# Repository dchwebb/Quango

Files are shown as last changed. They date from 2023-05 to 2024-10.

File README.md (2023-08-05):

# Quango
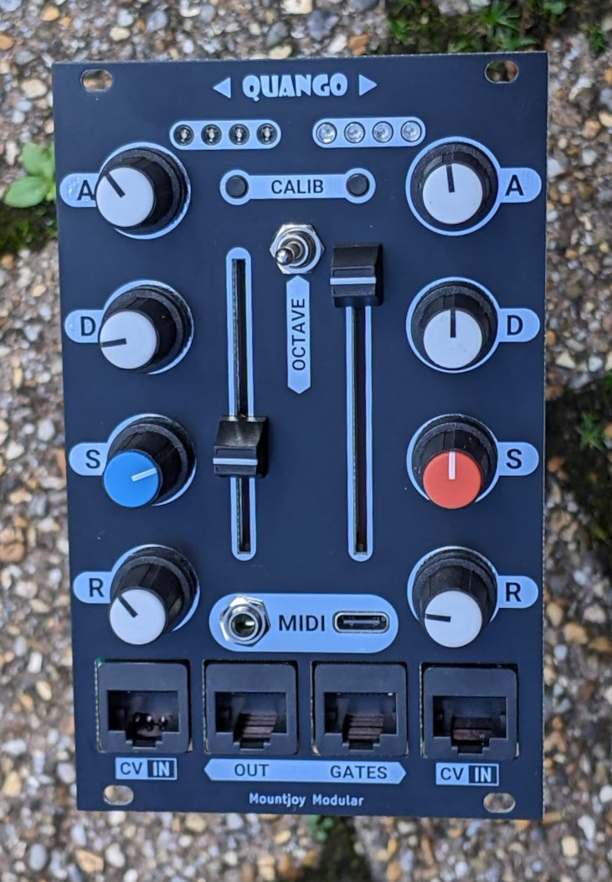
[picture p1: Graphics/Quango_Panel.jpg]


Quango
--------

Quango is a combined MIDI interface, VCA and envelope for controlling four voice polyphonic Eurorack Modular Oscillators. Polyphonic signal interconnections are made via RJ-45 cables (ie Ethernet cables).

Quango can control two VCOs simultaneously, supplying 1V/Octave pitch information and then shaping the returned audio using 8 ADSR envelopes controlling VCAs for each voice.

The MIDI interface receives both USB and serial MIDI data and also features a calibration mechanism where the pitch CV for each voice is adjusted to correct any tuning errors.

Each of the two channels uses an RJ-45 connector to send CV data on lines 1-4 and receive audio data on lines 5-8. The received audio data is used both for pitch calibration and sent into the ADSR-controlled VCAs.

Both channel voices are mixed and output onto an RJ-45 connection. Additionally each channel's four voices can be separately output on a header on the back of the unit. the gate signal for each voice is also output on an RJ-45 for controlling external envelopes etc.

Additional controls include an octave switch to allow channel B's CV range to be adjusted up or down an octave and a fader to control the overall level of each voice. LEDs show the current level of the VCA of each voice for each channel.

Technical
---------

Quango uses an STM32G473 microcontroller which handles the MIDI interfacing, generates 12-bit DAC signals to control the envelopes, reads the front panel controls from its internal ADCs and controls two external DACs for generating the pitch CV and one envelope (the microcontroller has 7 internal 12 bit DACs so the 8th envelope is supplied from an external 12 bit DAC).

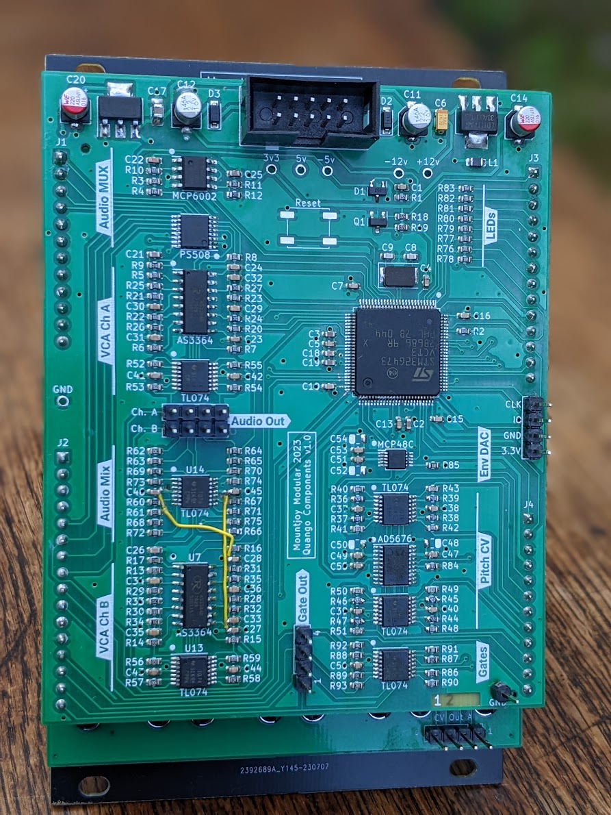
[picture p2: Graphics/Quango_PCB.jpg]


The 1V/Octave Pitch output is generated using an SPI controlled 16-bit 8 channel Analog Devices AD5676 DAC. A Microchip MCP48 12 bit DAC outputs the one envelope generated externally to the microcontroller. Alfa AS3364 quad linear VCAs are used for independent level control of each channel.

A PS508 audio multiplexer switches the 8 audio input channels to a single ADC channel on the microcontroller for pitch detection. Output level LEDs are controlled via PWM from the microcontroller.

Construction is a sandwich of three PCBs with a component board, a controls board and a panel. PCBs designed in Kicad v6.

[Components schematic](https://raw.githubusercontent.com/dchwebb/Quango/master/Hardware/Quango_Components.pdf)

[Controls schematic](https://raw.githubusercontent.com/dchwebb/Quango/master/Hardware/Quango_Controls.pdf)

In addition the the Eurorack +/-12V rails (which have polarity protection and filtering) a 5v rail is supplied using an AMS1117-5.0 LDO. A 3.3v rail is generated with an LM1117-3.3.

Errata
------

Version 1 of the component PCB had the power supply connections to op-amp U14 reversed.

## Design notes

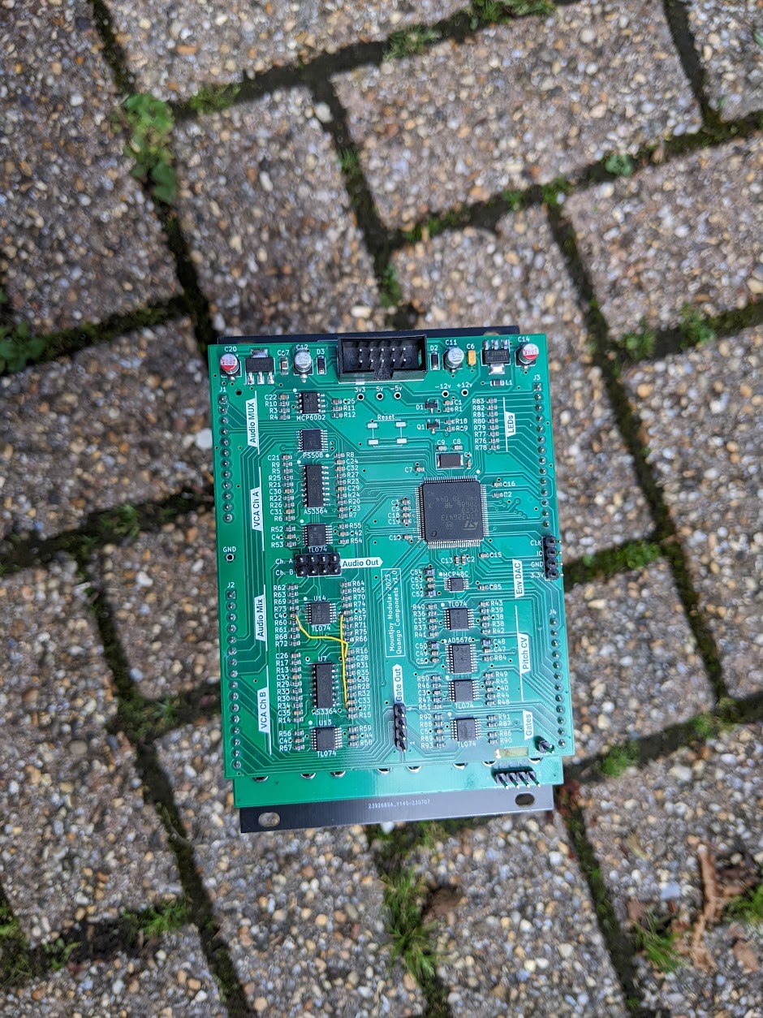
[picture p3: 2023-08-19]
Graphics/Quango_PCB2.jpg

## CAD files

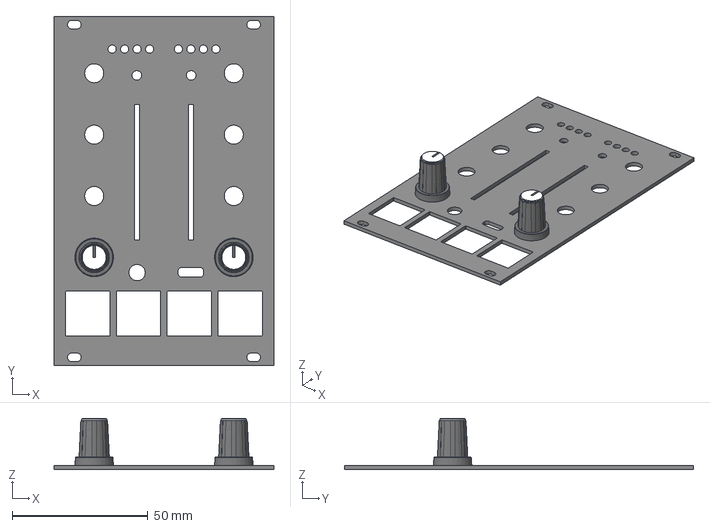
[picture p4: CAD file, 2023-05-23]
Hardware/Quango_Panel.step
81.0 x 128.5 x 18.9 mm
_autosave-Quango_Panel PCB

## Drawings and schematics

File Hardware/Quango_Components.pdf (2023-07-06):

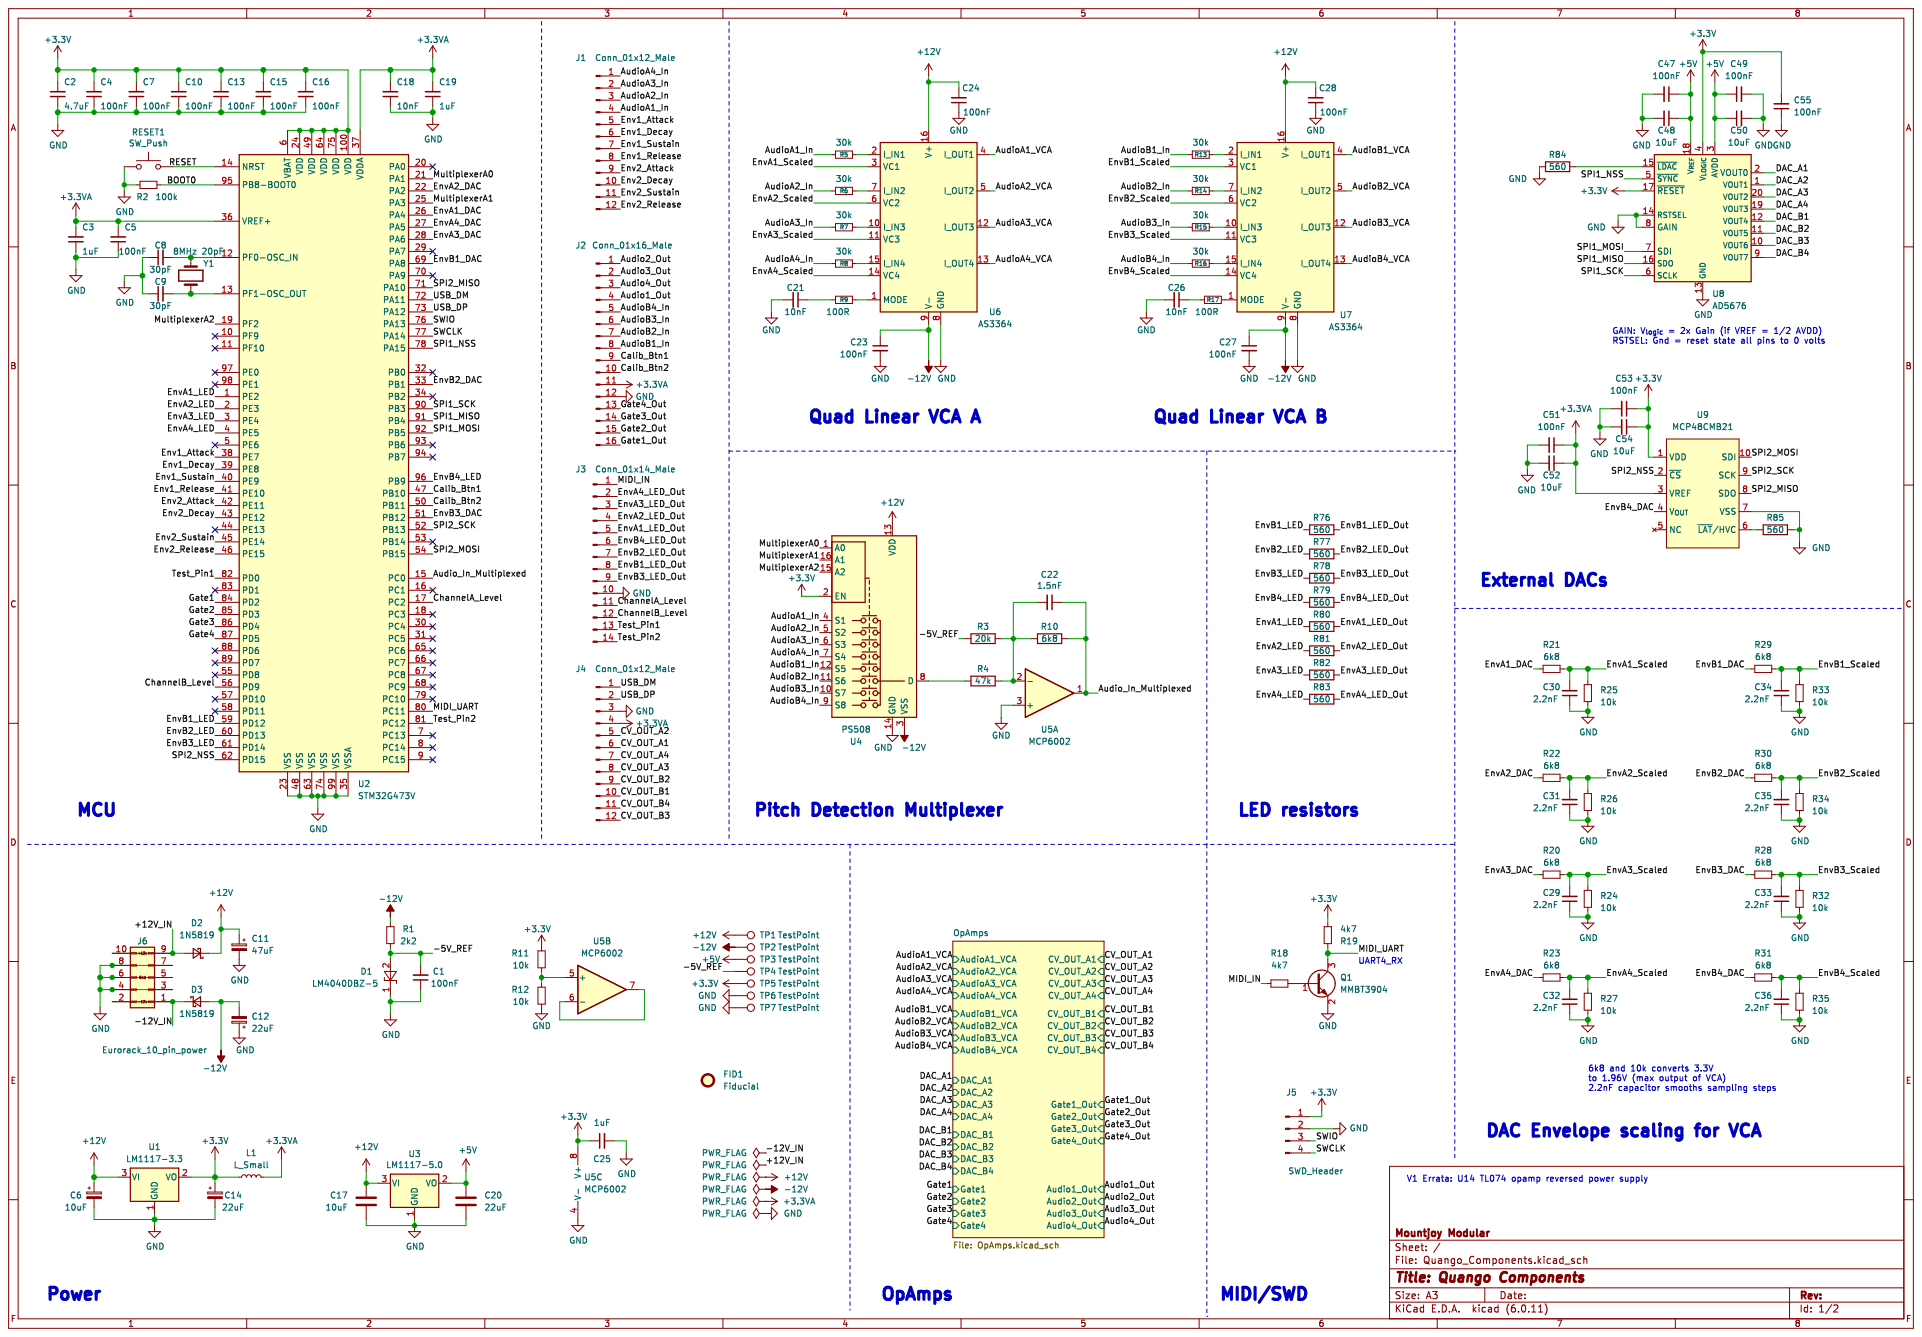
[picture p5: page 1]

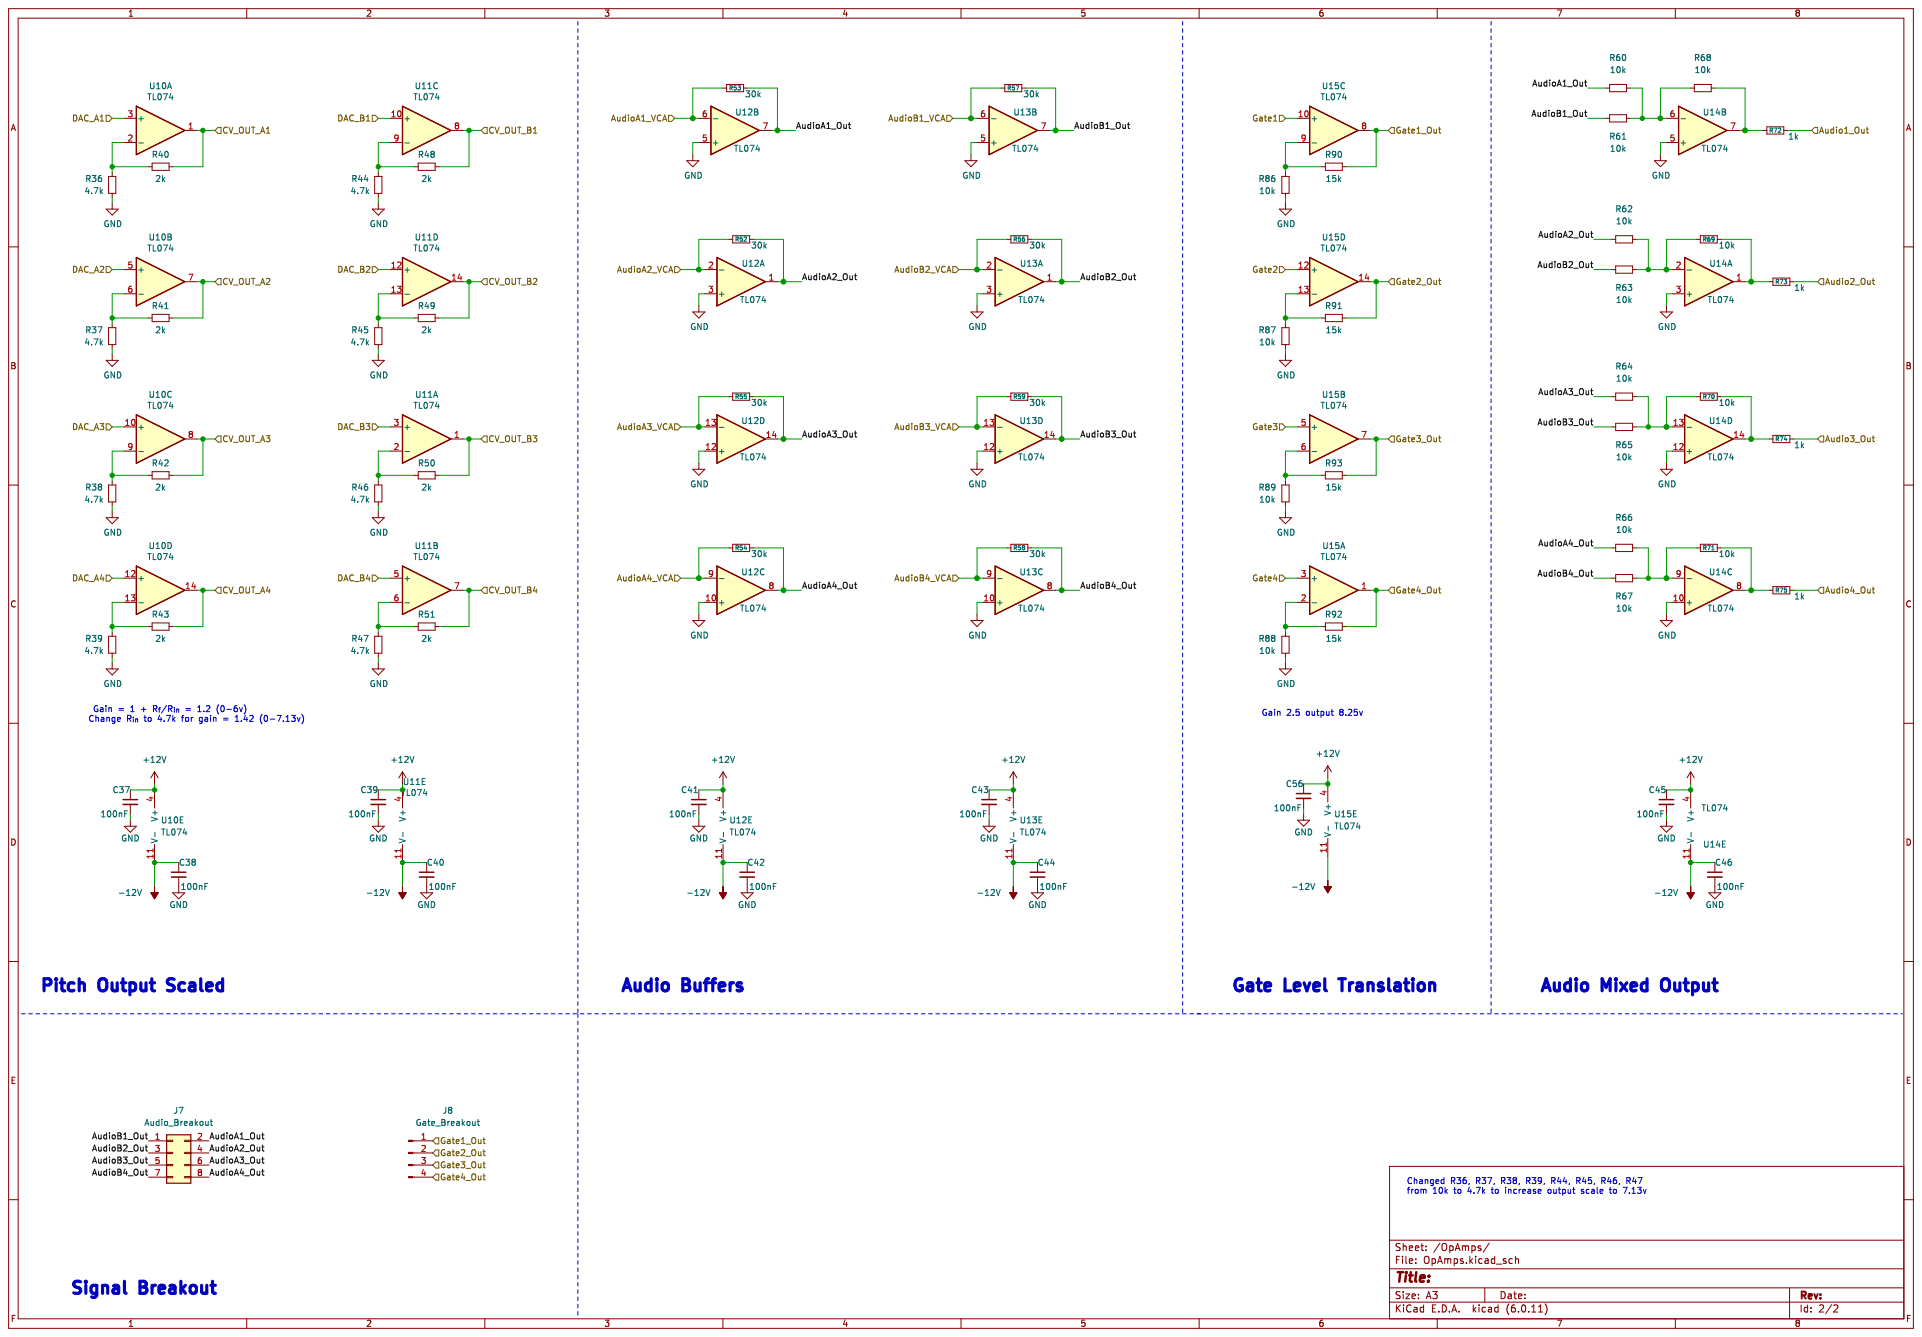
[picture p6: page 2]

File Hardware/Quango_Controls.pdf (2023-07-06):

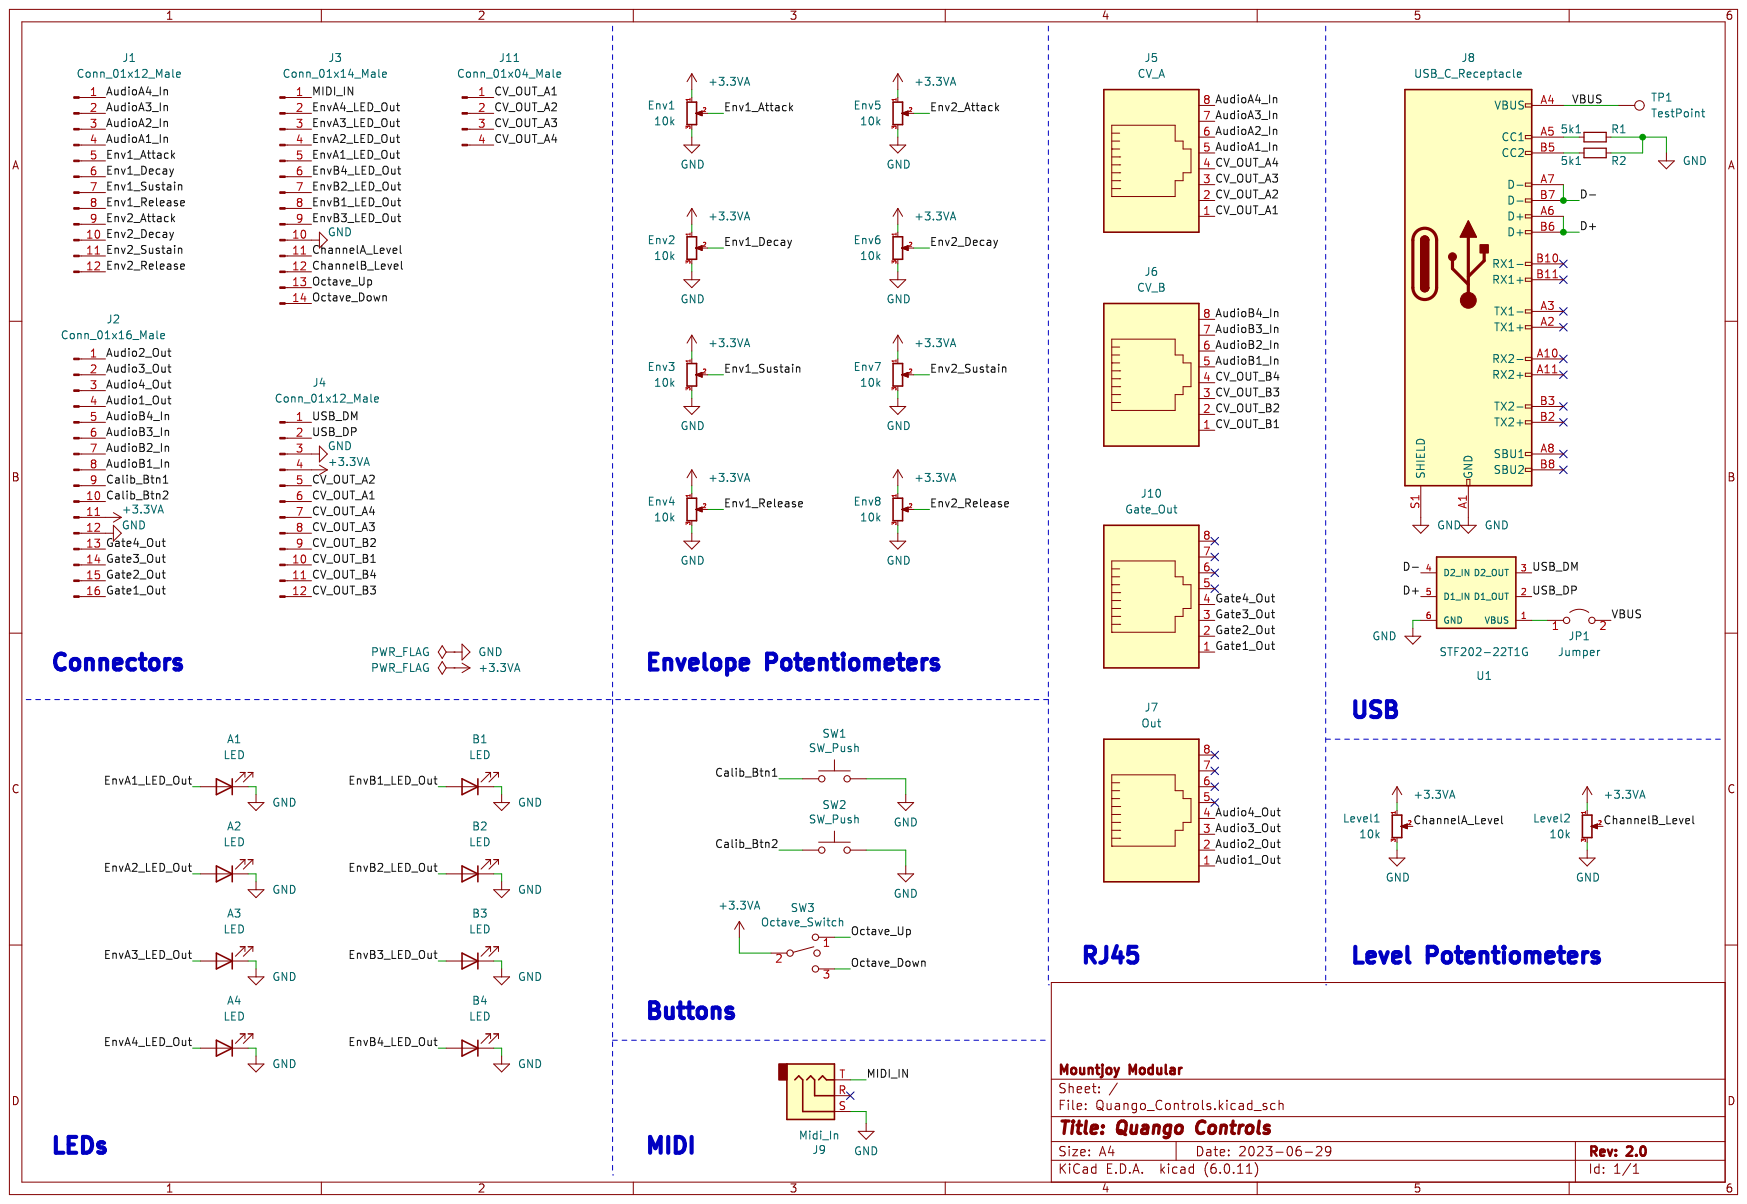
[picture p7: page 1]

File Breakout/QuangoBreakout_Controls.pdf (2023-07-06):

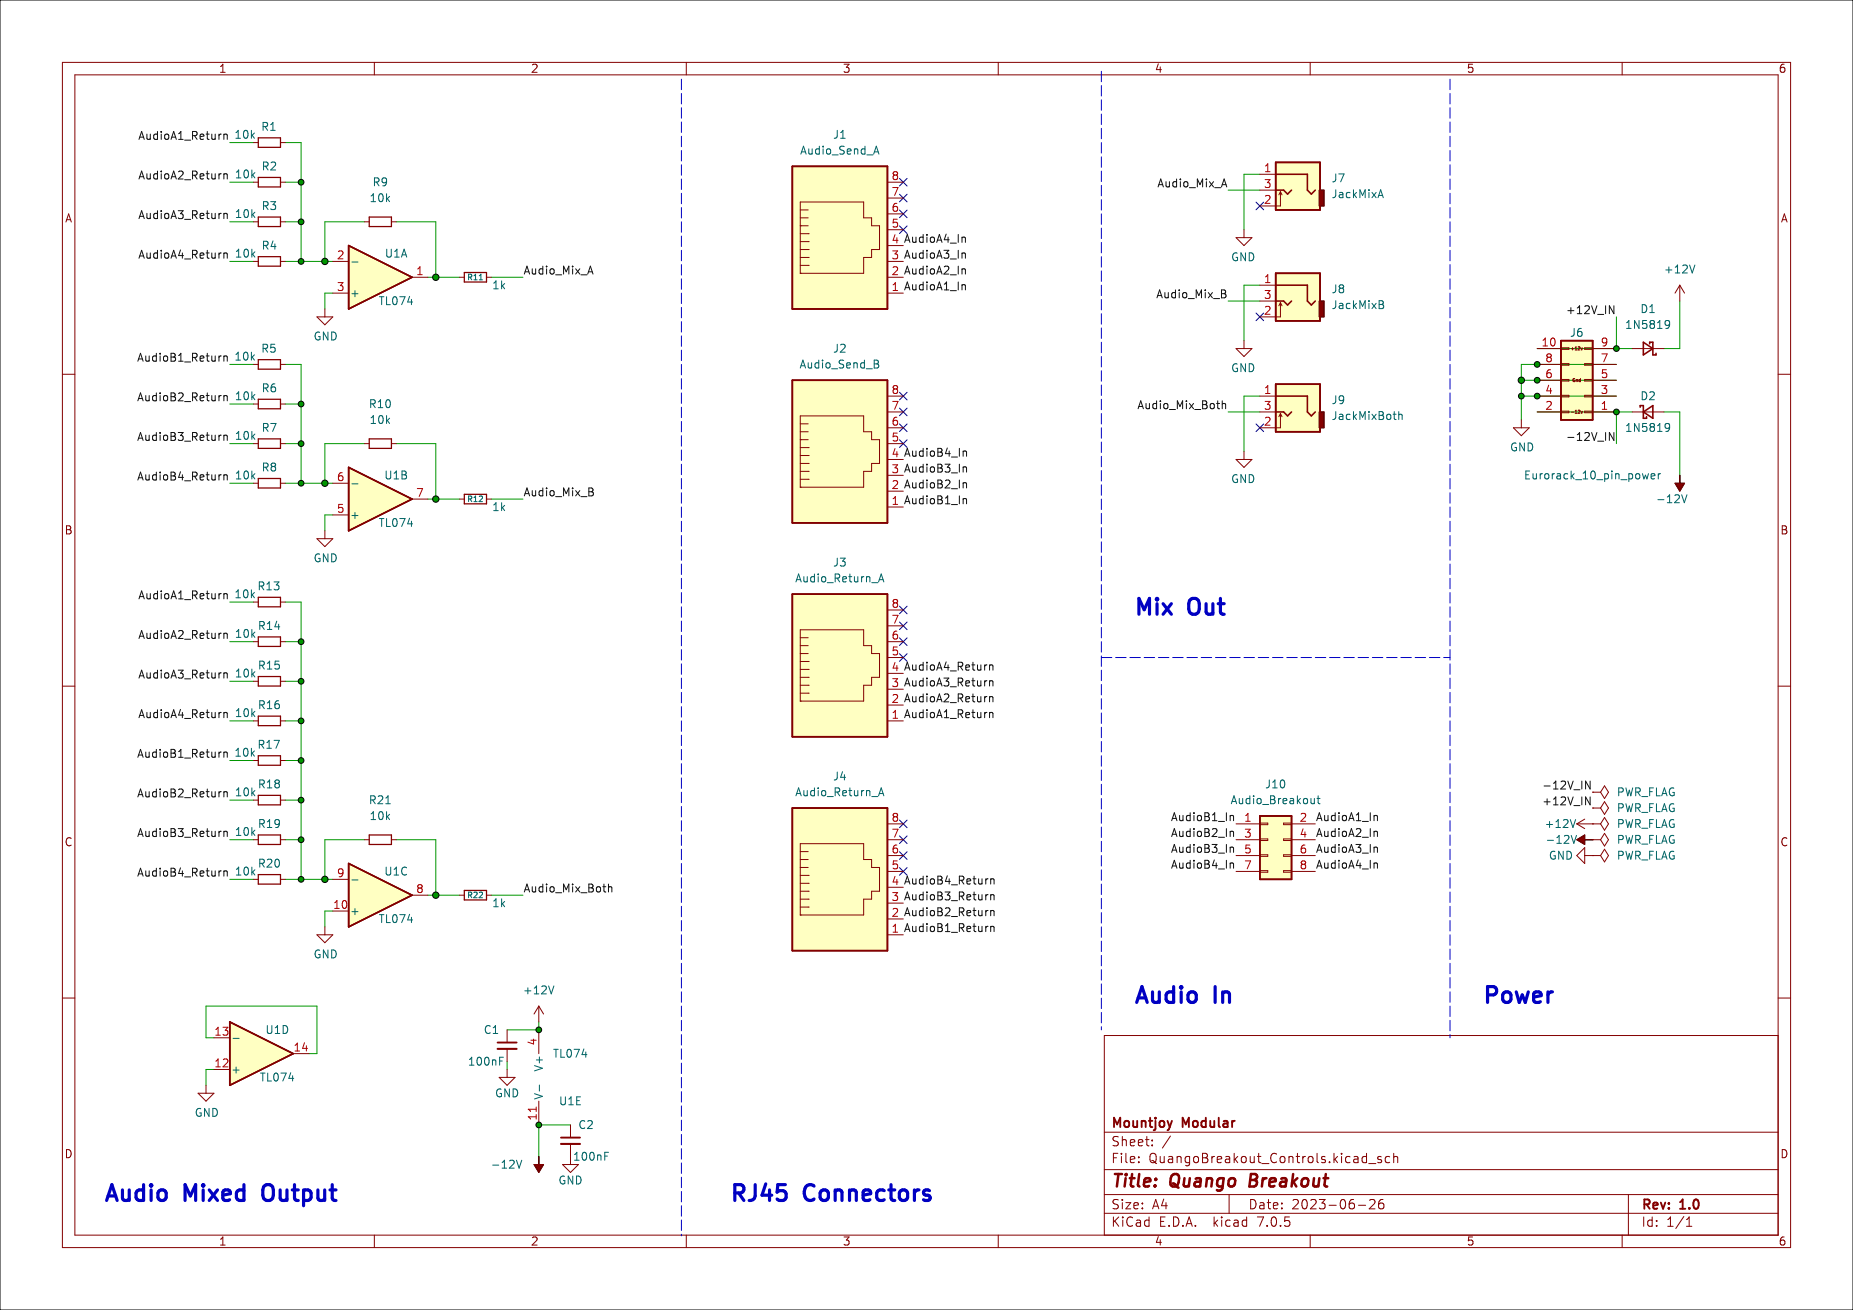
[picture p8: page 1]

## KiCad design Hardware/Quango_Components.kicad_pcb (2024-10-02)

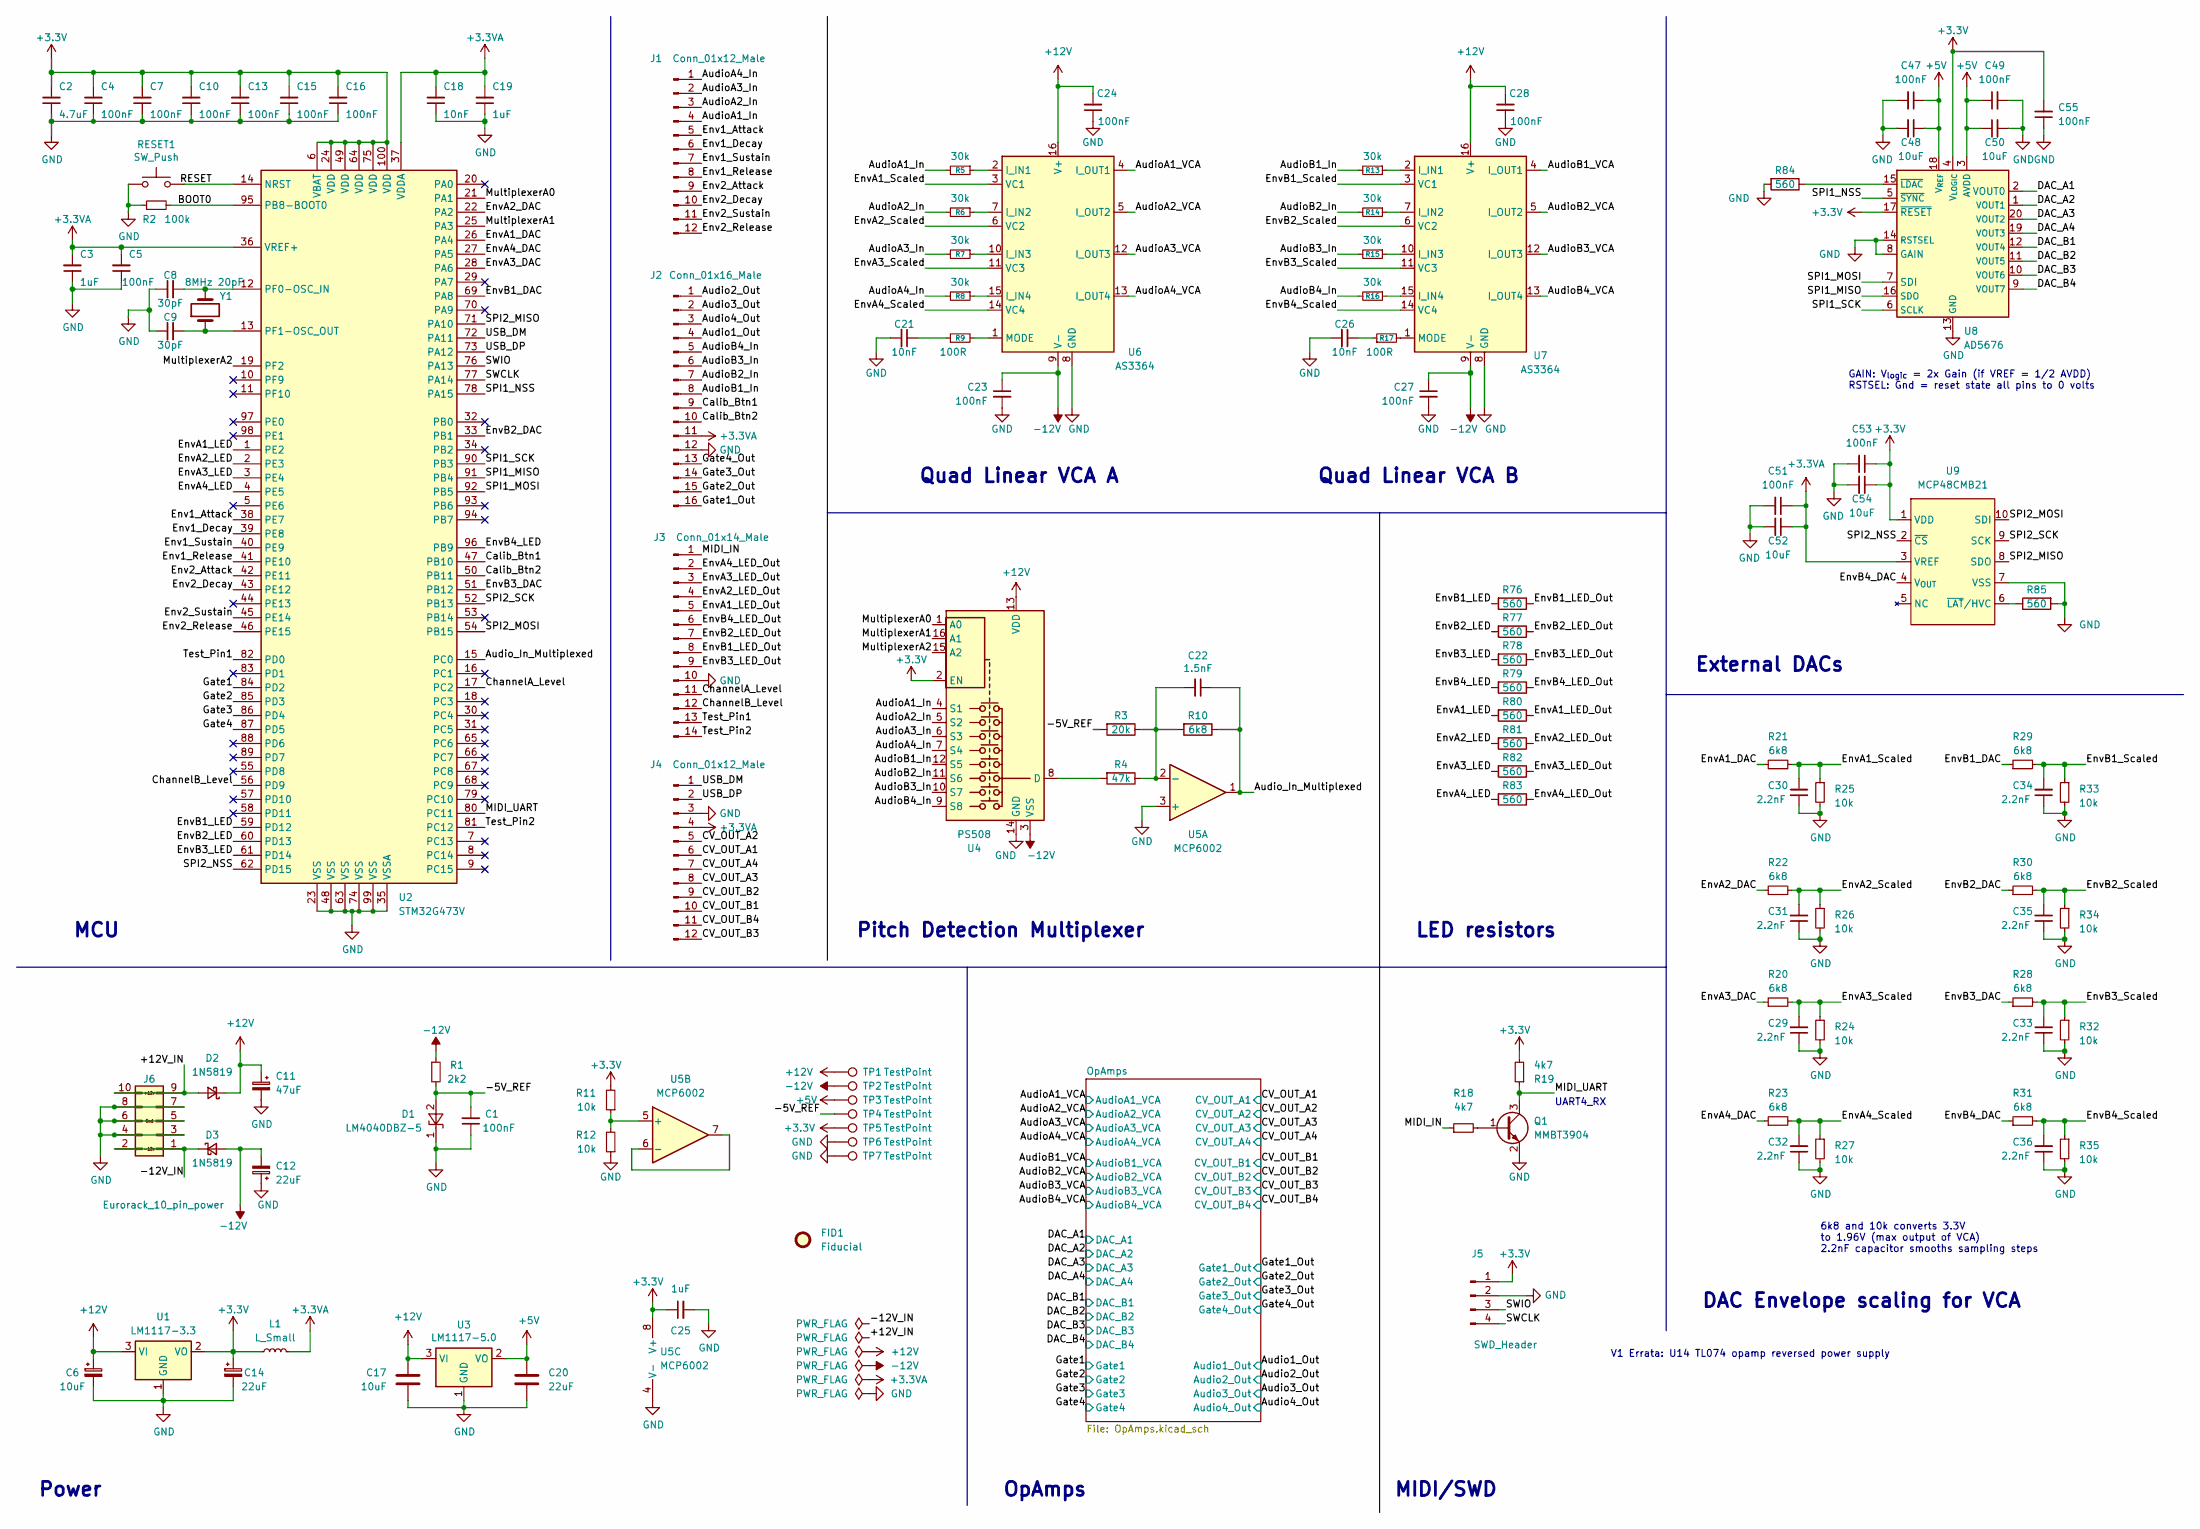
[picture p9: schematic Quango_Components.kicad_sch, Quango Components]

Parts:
C1, C4, C5, C7, C10, C13, C15, C16, C23, C24, C27, C28: 100nF; C_0603_1608Metric; Part_Number C14663
C2: 4.7uF; C_0603_1608Metric; Part_Number C19666
C3, C19: 1uF; C_0603_1608Metric; Part_Number C15849
C6, C17: 10uF; C_1206_3216Metric
C8, C9: 30pF; C_0603_1608Metric; Part_Number C22397
C11: 47uF; CP_Elec_4x5.8
C12, C14, C20: 22uF; CP_Elec_4x5.8
C18, C21, C26: 10nF; C_0603_1608Metric; Part_Number C57112
C22: 1.5nF; C_0603_1608Metric; Part_Number C1595
C25: 1uF; C_0603_1608Metric
C29, C30, C31, C32, C33, C34, C35, C36: 2.2nF; C_0603_1608Metric; Part_Number C1604
C47, C49, C51, C53, C55: 100nF; C_0603_1608Metric
C48, C50, C52, C54: 10uF; C_0805_2012Metric
D1: LM4040DBZ-5; SOT-23; Part_Number C156291
D2, D3: 1N5819; D_SOD-123
FID1: Fiducial; 4_Layer_Markers
J1, J4: Conn_01x12_Male; PinHeader_1x12_P2.54mm_Vertical
J2: Conn_01x16_Male; PinHeader_1x16_P2.54mm_Vertical
J3: Conn_01x14_Male; PinHeader_1x14_P2.54mm_Vertical
J5: SWD_Header; SWD_header
J6: Eurorack_10_pin_power; Eurorack_10_pin_header
L1: L_Small; L_0805_2012Metric_Pad1.05x1.20mm_HandSolder; Part_Number C1046
Q1: MMBT3904; SOT-23; Part_Number C20526
R1: 2k2; R_0603_1608Metric; Part_Number C4190
R2: 100k; R_0603_1608Metric; Part_Number C25803
R3: 20k; R_0603_1608Metric; Part_Number C4184
R4: 47k; R_0603_1608Metric; Part_Number C25819
R5, R6, R7, R8, R13, R14, R15, R16: 30k; R_0603_1608Metric; Part_Number C22984
R9, R17: 100R; R_0603_1608Metric; Part_Number C22775
R10, R20, R21, R22, R23, R28, R29, R30, R31: 6k8; R_0603_1608Metric; Part_Number C23212
R11, R12: 10k; R_0603_1608Metric; Part_Number C23162
R18, R19: 4k7; R_0603_1608Metric; Part_Number C23162
R24, R25, R26, R27, R32, R33, R34, R35: 10k; R_0603_1608Metric; Part_Number C25804
R76, R77, R78, R79, R80, R81, R82, R83, R84, R85: 560; R_0603_1608Metric; Part_Number C23212
RESET1: SW_Push; SW_SPST_EVQQ2
TP1, TP2, TP3, TP4, TP5, TP6, TP7: TestPoint; 1mm_Test_Point
U1: LM1117-3.3; SOT-223-3_TabPin2
U2: STM32G473V; LQFP-100_14x14mm_P0.5mm
U3: LM1117-5.0; SOT-223-3_TabPin2
U4: PS508; TSSOP-16_4.4x5mm_P0.65mm
U5: MCP6002; SOIC-8_3.9x4.9mm_P1.27mm
U6, U7: AS3364; SOIC-16_3.9x9.9mm_P1.27mm
U8: AD5676; TSSOP-20_4.4x6.5mm_P0.65mm
U9: MCP48CMB21; MSOP-10_3x3mm_P0.5mm
Y1: 8MHz 20pF; Crystal_SMD_0603-2Pin_6.0x3.5mm; Part_Number C115962

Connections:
+3.3V: C2.2, C4.2, C7.2, C10.2, C13.2, C14.1, C15.2, C16.2, C25.1, C53.1, C54.1, C55.2, J5.1, L1.1, R11.2, R19.2, TP5.1, U1.2 (VO), U2.6 (VBAT), U2.24 (VDD), U2.49 (VDD), U2.64 (VDD), U2.75 (VDD), U2.100 (VDD), U4.2 (EN), U5.8 (V+), U8.4 (V_{LOGIC}), U8.17 (~RESET), U9.1 (VDD)
+3.3VA: C3.2, C5.2, C18.2, C19.2, C51.1, C52.1, J2.11, J4.4, L1.2, U2.36 (VREF+), U2.37 (VDDA), U9.3 (VREF)
+5V: C20.1, C47.1, C48.1, C49.1, C50.1, TP3.1, U3.2 (VO), U8.3 (AVDD), U8.18 (V_{REF})
+12V: C6.1, C11.1, C17.1, C24.2, C28.2, D2.1 (K), TP1.1, U1.3 (VI), U3.3 (VI), U4.13 (VDD), U6.16 (V+), U7.16 (V+); also elsewhere on the board
-12V: C12.2, C23.1, C27.1, D3.2 (A), R1.1, TP2.1, U4.3 (VSS), U6.9 (V-), U7.9 (V-); also elsewhere on the board
/+12V_IN: D2.2 (A), J6.9, J6.10
/-5V_REF: C1.2, D1.2 (A), R1.2, R3.2, TP4.1
/-12V_IN: D3.1 (K), J6.1, J6.2
/Audio1_Out: J2.4; also elsewhere on the board
/Audio2_Out: J2.1; also elsewhere on the board
/Audio3_Out: J2.2; also elsewhere on the board
/Audio4_Out: J2.3; also elsewhere on the board
/AudioA1_In: J1.4, R5.2, U4.4 (S1)
/AudioA1_VCA: U6.4 (I_OUT1); also elsewhere on the board
/AudioA2_In: J1.3, R6.2, U4.5 (S2)
/AudioA2_VCA: U6.5 (I_OUT2); also elsewhere on the board
/AudioA3_In: J1.2, R7.2, U4.6 (S3)
/AudioA3_VCA: U6.12 (I_OUT3); also elsewhere on the board
/AudioA4_In: J1.1, R8.2, U4.7 (S4)
/AudioA4_VCA: U6.13 (I_OUT4); also elsewhere on the board
/AudioB1_In: J2.8, R13.2, U4.12 (S5)
/AudioB1_VCA: U7.4 (I_OUT1); also elsewhere on the board
/AudioB2_In: J2.7, R14.2, U4.11 (S6)
/AudioB2_VCA: U7.5 (I_OUT2); also elsewhere on the board
/AudioB3_In: J2.6, R15.2, U4.10 (S7)
/AudioB3_VCA: U7.12 (I_OUT3); also elsewhere on the board
/AudioB4_In: J2.5, R16.2, U4.9 (S8)
/AudioB4_VCA: U7.13 (I_OUT4); also elsewhere on the board
/Audio_In_Multiplexed: C22.1, R10.1, U2.15 (PC0), U5.1
/BOOT0: R2.2, U2.95 (PB8-BOOT0)
/CV_OUT_A1: J4.6; also elsewhere on the board
/CV_OUT_A2: J4.5; also elsewhere on the board
/CV_OUT_A3: J4.8; also elsewhere on the board
/CV_OUT_A4: J4.7; also elsewhere on the board
/CV_OUT_B1: J4.10; also elsewhere on the board
/CV_OUT_B2: J4.9; also elsewhere on the board
/CV_OUT_B3: J4.12; also elsewhere on the board
/CV_OUT_B4: J4.11; also elsewhere on the board
/Calib_Btn1: J2.9, U2.47 (PB10)
/Calib_Btn2: J2.10, U2.50 (PB11)
/ChannelA_Level: J3.11, U2.17 (PC2)
/ChannelB_Level: J3.12, U2.56 (PD9)
/DAC_A1: U8.2 (VOUT0); also elsewhere on the board
/DAC_A2: U8.1 (VOUT1); also elsewhere on the board
/DAC_A3: U8.20 (VOUT2); also elsewhere on the board
/DAC_A4: U8.19 (VOUT3); also elsewhere on the board
/DAC_B1: U8.12 (VOUT4); also elsewhere on the board
/DAC_B2: U8.11 (VOUT5); also elsewhere on the board
/DAC_B3: U8.10 (VOUT6); also elsewhere on the board
/DAC_B4: U8.9 (VOUT7); also elsewhere on the board
/Env1_Attack: J1.5, U2.38 (PE7)
/Env1_Decay: J1.6, U2.39 (PE8)
/Env1_Release: J1.8, U2.41 (PE10)
/Env1_Sustain: J1.7, U2.40 (PE9)
/Env2_Attack: J1.9, U2.42 (PE11)
/Env2_Decay: J1.10, U2.43 (PE12)
/Env2_Release: J1.12, U2.46 (PE15)
/Env2_Sustain: J1.11, U2.45 (PE14)
/EnvA1_DAC: R21.1, U2.26 (PA4)
/EnvA1_LED: R80.2, U2.1 (PE2)
/EnvA1_LED_Out: J3.5, R80.1
/EnvA1_Scaled: C30.2, R21.2, R25.1, U6.3 (VC1)
/EnvA2_DAC: R22.1, U2.22 (PA2)
/EnvA2_LED: R81.2, U2.2 (PE3)
/EnvA2_LED_Out: J3.4, R81.1
/EnvA2_Scaled: C31.2, R22.2, R26.1, U6.6 (VC2)
/EnvA3_DAC: R20.1, U2.28 (PA6)
/EnvA3_LED: R82.2, U2.3 (PE4)
/EnvA3_LED_Out: J3.3, R82.1
/EnvA3_Scaled: C29.2, R20.2, R24.1, U6.11 (VC3)
/EnvA4_DAC: R23.1, U2.27 (PA5)
/EnvA4_LED: R83.2, U2.4 (PE5)
/EnvA4_LED_Out: J3.2, R83.1
/EnvA4_Scaled: C32.2, R23.2, R27.1, U6.14 (VC4)
/EnvB1_DAC: R29.1, U2.69 (PA8)
/EnvB1_LED: R76.2, U2.59 (PD12)
/EnvB1_LED_Out: J3.8, R76.1
/EnvB1_Scaled: C34.2, R29.2, R33.1, U7.3 (VC1)
/EnvB2_DAC: R30.1, U2.33 (PB1)
/EnvB2_LED: R77.2, U2.60 (PD13)
/EnvB2_LED_Out: J3.7, R77.1
/EnvB2_Scaled: C35.2, R30.2, R34.1, U7.6 (VC2)
/EnvB3_DAC: R28.1, U2.51 (PB12)
/EnvB3_LED: R78.2, U2.61 (PD14)
/EnvB3_LED_Out: J3.9, R78.1
/EnvB3_Scaled: C33.2, R28.2, R32.1, U7.11 (VC3)
/EnvB4_DAC: R31.1, U9.4 (V_{OUT})
/EnvB4_LED: R79.2, U2.96 (PB9)
/EnvB4_LED_Out: J3.6, R79.1
/EnvB4_Scaled: C36.2, R31.2, R35.1, U7.14 (VC4)
/Gate1: U2.84 (PD2); also elsewhere on the board
/Gate1_Out: J2.16; also elsewhere on the board
/Gate2: U2.85 (PD3); also elsewhere on the board
/Gate2_Out: J2.15; also elsewhere on the board
/Gate3: U2.86 (PD4); also elsewhere on the board
/Gate3_Out: J2.14; also elsewhere on the board
/Gate4: U2.87 (PD5); also elsewhere on the board
/Gate4_Out: J2.13; also elsewhere on the board
/MIDI_IN: J3.1, R18.1
/MIDI_UART: Q1.3 (C), R19.1, U2.80 (PC11)
/MultiplexerA0: U2.21 (PA1), U4.1 (A0)
/MultiplexerA1: U2.25 (PA3), U4.16 (A1)
/MultiplexerA2: U2.19 (PF2), U4.15 (A2)
/RESET: RESET1.1, U2.14 (NRST)
/SPI1_MISO: U2.91 (PB4), U8.16 (SDO)
/SPI1_MOSI: U2.92 (PB5), U8.7 (SDI)
/SPI1_NSS: U2.78 (PA15), U8.5 (~SYNC)
/SPI1_SCK: U2.90 (PB3), U8.6 (SCLK)
/SPI2_MISO: U2.71 (PA10), U9.8 (SDO)
/SPI2_MOSI: U2.54 (PB15), U9.10 (SDI)
/SPI2_NSS: U2.62 (PD15), U9.2 (~CS)
/SPI2_SCK: U2.52 (PB13), U9.9 (SCK)
/SWCLK: J5.4, U2.77 (PA14)
/SWIO: J5.3, U2.76 (PA13)
/Test_Pin1: J3.13, U2.82 (PD0)
/Test_Pin2: J3.14, U2.81 (PC12)
/USB_DM: J4.1, U2.72 (PA11)
/USB_DP: J4.2, U2.73 (PA12)
GND: C1.1, C2.1, C3.1, C4.1, C5.1, C6.2, C7.1, C8.1, C9.1, C10.1, C11.2, C12.1, C13.1, C14.2, C15.1, C16.1, C17.2, C18.1, C19.1, C20.2, C21.2, C23.2, C24.1, C25.2, C26.2, C27.2, C28.1, C29.1, C30.1, C31.1, C32.1, C33.1, C34.1, C35.1, C36.1, C47.2, C48.2, C49.2, C50.2, C51.2, C52.2, C53.2, C54.2, C55.1, D1.1 (K), J2.12, J3.10, J4.3, J5.2, J6.3, J6.4, J6.5, J6.6, J6.7, J6.8, Q1.2 (E), R2.1, R12.1, R24.2, R25.2, R26.2, R27.2, R32.2, R33.2, R34.2, R35.2, R84.2, R85.2, RESET1.2, TP6.1, TP7.1, U1.1 (GND), U2.23 (VSS), U2.35 (VSSA), U2.48 (VSS), U2.63 (VSS), U2.74 (VSS), U2.99 (VSS), U3.1 (GND), U4.14 (GND), U5.3 (+), U5.4 (V-), U6.8 (GND), U7.8 (GND), U8.8 (GAIN), U8.13 (GND), U8.14 (RSTSEL), U9.7 (VSS); also elsewhere on the board
unnamed: C21.1, R9.1
unnamed: C26.1, R17.1
unnamed: Q1.1 (B), R18.2
unnamed: C8.2, U2.12 (PF0-OSC_IN), Y1.2
unnamed: C9.2, U2.13 (PF1-OSC_OUT), Y1.1
unnamed: R4.2, U4.8 (D)
unnamed: C22.2, R3.1, R4.1, R10.2, U5.2 (-)
unnamed: R11.1, R12.2, U5.5 (+)
unnamed: U5.6 (-), U5.7
unnamed: R5.1, U6.2 (I_IN1)
unnamed: R6.1, U6.7 (I_IN2)
unnamed: R7.1, U6.10 (I_IN3)
unnamed: R8.1, U6.15 (I_IN4)
unnamed: R9.2, U6.1 (MODE)
unnamed: R13.1, U7.2 (I_IN1)
unnamed: R14.1, U7.7 (I_IN2)
unnamed: R15.1, U7.10 (I_IN3)
unnamed: R16.1, U7.15 (I_IN4)
unnamed: R17.2, U7.1 (MODE)
unnamed: R84.1, U8.15 (~LDAC)
unnamed: R85.1, U9.6 (~LAT/HVC)

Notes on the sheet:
Pitch Detection Multiplexer
DAC Envelope scaling for VCA
Power
V1 Errata: U14 TL074 opamp reversed power supply
MCU
UART4_RX
GAIN: V_{logic} = 2x Gain (if VREF = 1/2 AVDD) RSTSEL: Gnd = reset state all pins to 0 volts
6k8 and 10k converts 3.3V to 1.96V (max output of VCA) 2.2nF capacitor smooths sampling steps
LED resistors
OpAmps
External DACs
Quad Linear VCA B
MIDI/SWD
Quad Linear VCA A

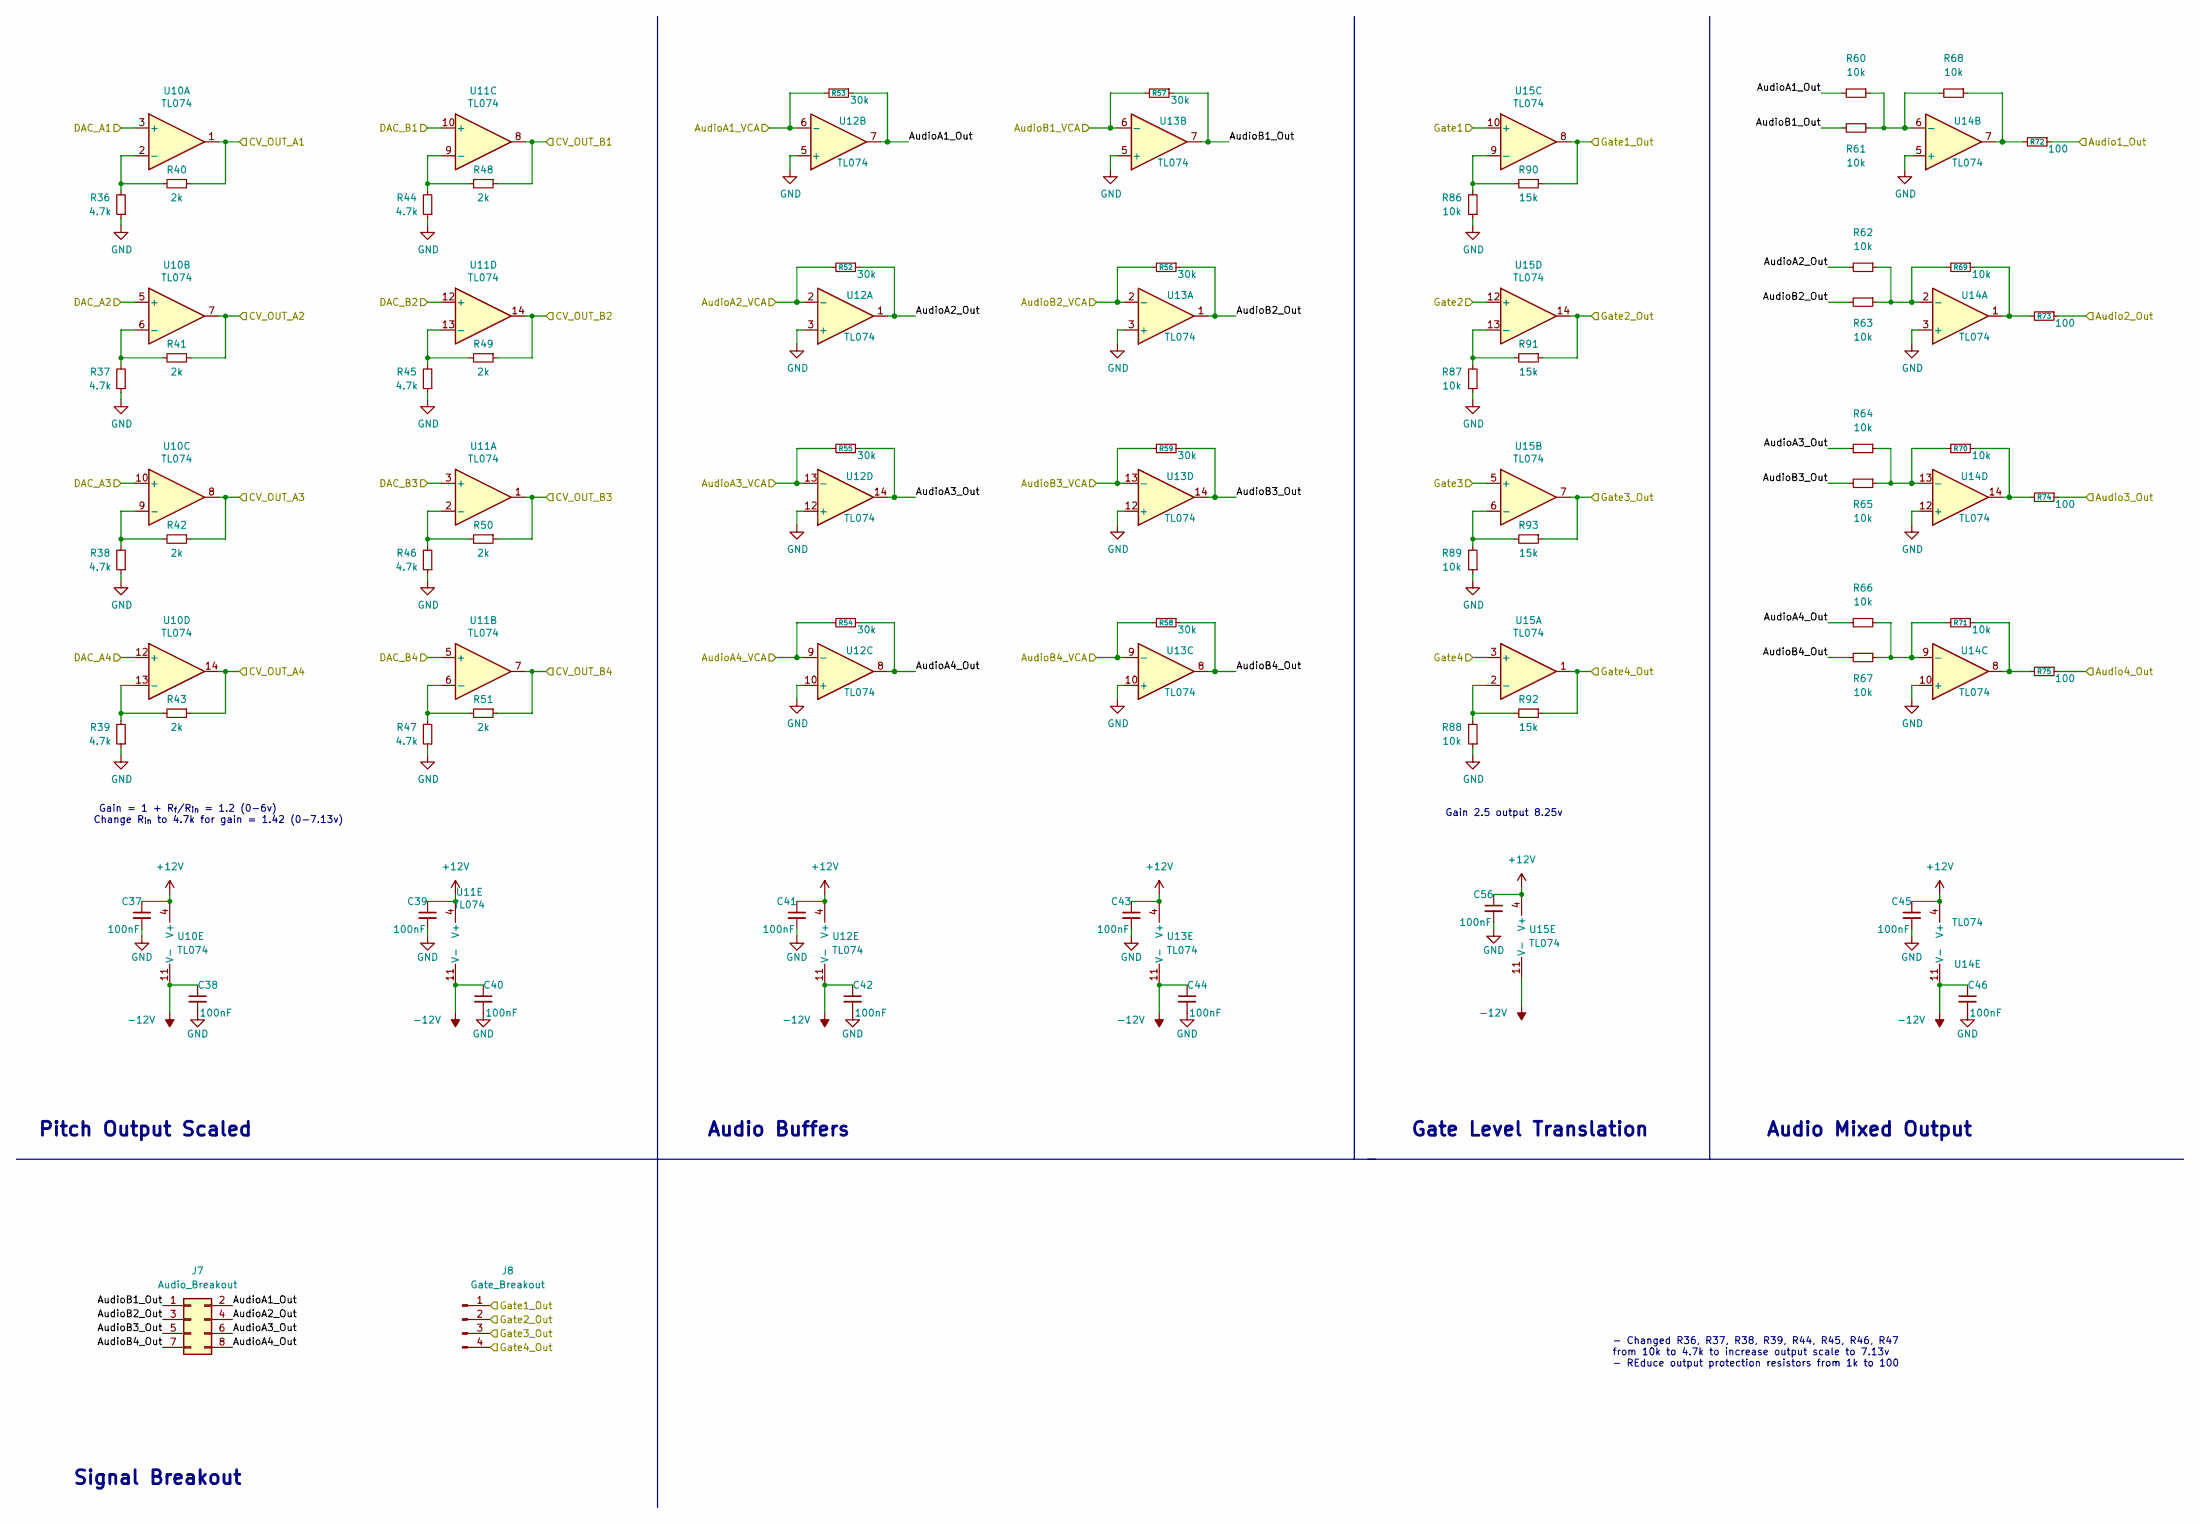
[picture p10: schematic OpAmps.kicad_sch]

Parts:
C37, C38, C39, C40, C41, C42, C43, C44, C45, C46, C56: 100nF; C_0603_1608Metric; Part_Number C23630
J7: Audio_Breakout; PinHeader_2x04_P2.54mm_Vertical
J8: Gate_Breakout; PinHeader_1x04_P2.54mm_Vertical
R36, R37, R38, R39, R44, R45, R46, R47: 4.7k; R_0603_1608Metric
R40, R41, R42, R43, R48, R49, R50, R51: 2k; R_0603_1608Metric
R52, R53, R54, R55, R56, R57, R58, R59: 30k; R_0603_1608Metric; Part_Number C22984
R60, R61, R62, R63, R64, R65, R66, R67, R68, R69, R70, R71: 10k; R_0603_1608Metric; Part_Number C22984
R72, R73, R74, R75: 100; R_0603_1608Metric; Part_Number C21190
R86, R87, R88, R89: 10k; R_0603_1608Metric
R90, R91, R92, R93: 15k; R_0603_1608Metric
U10, U11, U12, U13, U14, U15: TL074; TSSOP-14_4.4x5mm_P0.65mm

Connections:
+12V: C37.1, C39.1, C41.1, C43.1, C45.1, C56.1, U10.4 (V+), U11.4 (V+), U12.4 (V+), U13.4 (V+), U14.4 (V+), U15.4 (V+); also elsewhere on the board
-12V: C38.1, C40.1, C42.1, C44.1, C46.1, U10.11 (V-), U11.11 (V-), U12.11 (V-), U13.11 (V-), U14.11 (V-), U15.11 (V-); also elsewhere on the board
/Audio1_Out: R72.1; also elsewhere on the board
/Audio2_Out: R73.1; also elsewhere on the board
/Audio3_Out: R74.1; also elsewhere on the board
/Audio4_Out: R75.1; also elsewhere on the board
/AudioA1_VCA: R53.2, U12.6 (-); also elsewhere on the board
/AudioA2_VCA: R52.2, U12.2 (-); also elsewhere on the board
/AudioA3_VCA: R55.2, U12.13 (-); also elsewhere on the board
/AudioA4_VCA: R54.2, U12.9 (-); also elsewhere on the board
/AudioB1_VCA: R57.2, U13.6 (-); also elsewhere on the board
/AudioB2_VCA: R56.2, U13.2 (-); also elsewhere on the board
/AudioB3_VCA: R59.2, U13.13 (-); also elsewhere on the board
/AudioB4_VCA: R58.2, U13.9 (-); also elsewhere on the board
/CV_OUT_A1: R40.1, U10.1; also elsewhere on the board
/CV_OUT_A2: R41.1, U10.7; also elsewhere on the board
/CV_OUT_A3: R42.1, U10.8; also elsewhere on the board
/CV_OUT_A4: R43.1, U10.14; also elsewhere on the board
/CV_OUT_B1: R48.1, U11.8; also elsewhere on the board
/CV_OUT_B2: R49.1, U11.14; also elsewhere on the board
/CV_OUT_B3: R50.1, U11.1; also elsewhere on the board
/CV_OUT_B4: R51.1, U11.7; also elsewhere on the board
/DAC_A1: U10.3 (+); also elsewhere on the board
/DAC_A2: U10.5 (+); also elsewhere on the board
/DAC_A3: U10.10 (+); also elsewhere on the board
/DAC_A4: U10.12 (+); also elsewhere on the board
/DAC_B1: U11.10 (+); also elsewhere on the board
/DAC_B2: U11.12 (+); also elsewhere on the board
/DAC_B3: U11.3 (+); also elsewhere on the board
/DAC_B4: U11.5 (+); also elsewhere on the board
/Gate1: U15.10 (+); also elsewhere on the board
/Gate1_Out: J8.1, R90.1, U15.8; also elsewhere on the board
/Gate2: U15.12 (+); also elsewhere on the board
/Gate2_Out: J8.2, R91.1, U15.14; also elsewhere on the board
/Gate3: U15.5 (+); also elsewhere on the board
/Gate3_Out: J8.3, R93.1, U15.7; also elsewhere on the board
/Gate4: U15.3 (+); also elsewhere on the board
/Gate4_Out: J8.4, R92.1, U15.1; also elsewhere on the board
/OpAmps/AudioA1_Out: J7.2, R53.1, R60.2, U12.7
/OpAmps/AudioA2_Out: J7.4, R52.1, R62.2, U12.1
/OpAmps/AudioA3_Out: J7.6, R55.1, R64.2, U12.14
/OpAmps/AudioA4_Out: J7.8, R54.1, R66.2, U12.8
/OpAmps/AudioB1_Out: J7.1, R57.1, R61.2, U13.7
/OpAmps/AudioB2_Out: J7.3, R56.1, R63.2, U13.1
/OpAmps/AudioB3_Out: J7.5, R59.1, R65.2, U13.14
/OpAmps/AudioB4_Out: J7.7, R58.1, R67.2, U13.8
GND: C37.2, C38.2, C39.2, C40.2, C41.2, C42.2, C43.2, C44.2, C45.2, C46.2, C56.2, R36.1, R37.1, R38.1, R39.1, R44.1, R45.1, R46.1, R47.1, R86.1, R87.1, R88.1, R89.1, U12.3 (+), U12.5 (+), U12.10 (+), U12.12 (+), U13.3 (+), U13.5 (+), U13.10 (+), U13.12 (+), U14.3 (+), U14.5 (+), U14.10 (+), U14.12 (+); also elsewhere on the board
unnamed: R68.1, R72.2, U14.7
unnamed: R69.1, R73.2, U14.1
unnamed: R70.1, R74.2, U14.14
unnamed: R71.1, R75.2, U14.8
unnamed: R36.2, R40.2, U10.2 (-)
unnamed: R37.2, R41.2, U10.6 (-)
unnamed: R38.2, R42.2, U10.9 (-)
unnamed: R39.2, R43.2, U10.13 (-)
unnamed: R46.2, R50.2, U11.2 (-)
unnamed: R47.2, R51.2, U11.6 (-)
unnamed: R44.2, R48.2, U11.9 (-)
unnamed: R45.2, R49.2, U11.13 (-)
unnamed: R62.1, R63.1, R69.2, U14.2 (-)
unnamed: R60.1, R61.1, R68.2, U14.6 (-)
unnamed: R66.1, R67.1, R71.2, U14.9 (-)
unnamed: R64.1, R65.1, R70.2, U14.13 (-)
unnamed: R88.2, R92.2, U15.2 (-)
unnamed: R89.2, R93.2, U15.6 (-)
unnamed: R86.2, R90.2, U15.9 (-)
unnamed: R87.2, R91.2, U15.13 (-)

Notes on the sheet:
Signal Breakout
Gate Level Translation
Audio Buffers
Pitch Output Scaled
Audio Mixed Output
Gain 2.5 output 8.25v
Gain = 1 + R_{f}/R_{in} = 1.2 (0-6v) Change R_{in} to 4.7k for gain = 1.42 (0-7.13v)
- Changed R36, R37, R38, R39, R44, R45, R46, R47 from 10k to 4.7k to increase output scale to 7.13v - REduce output protection resistors from 1k to 100

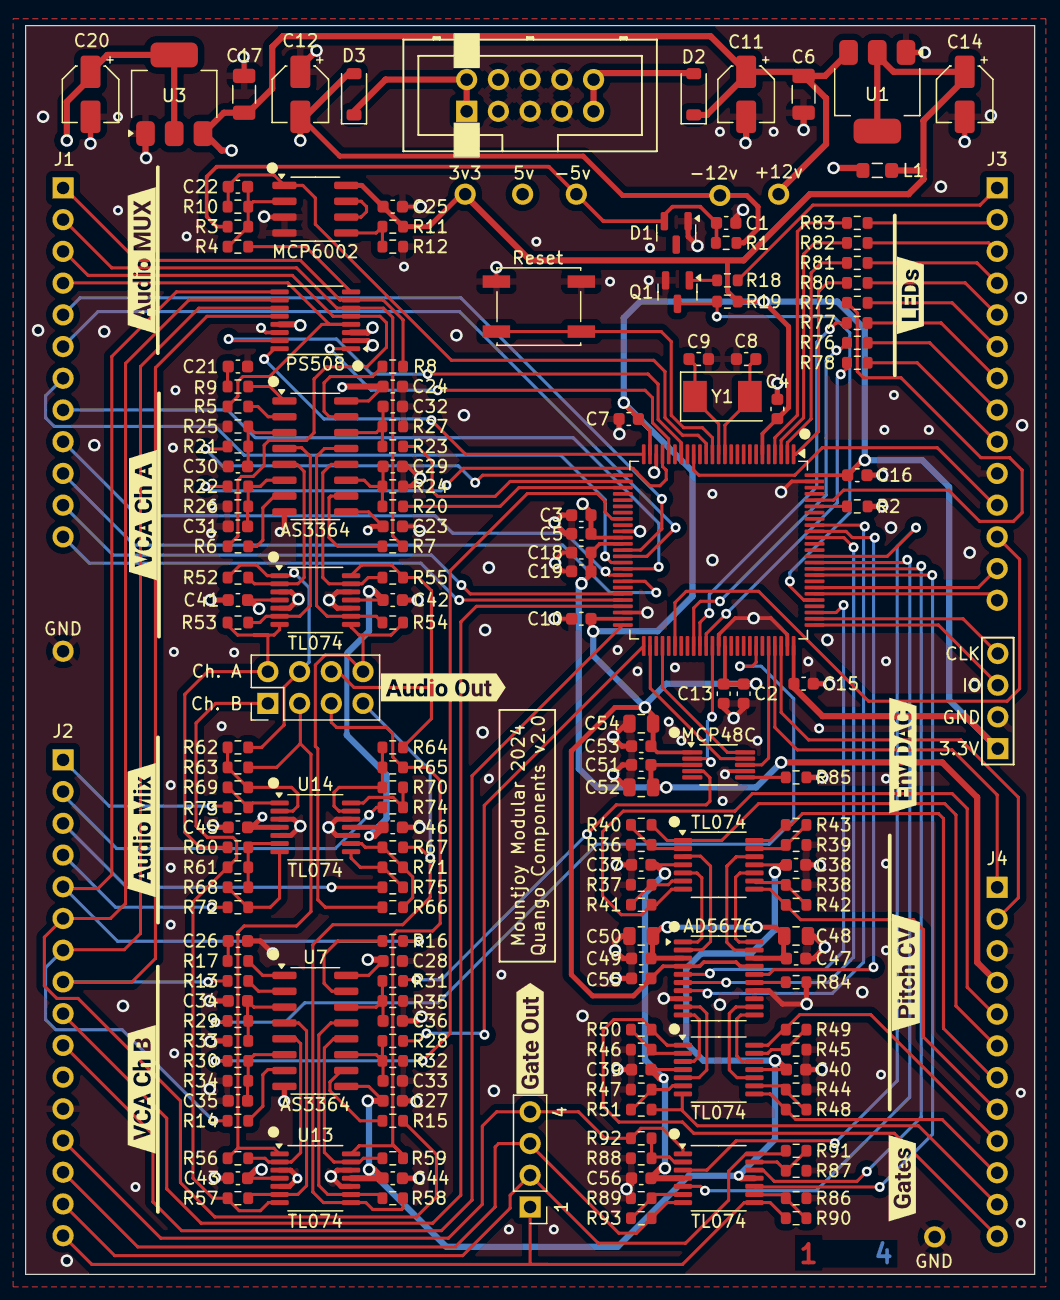
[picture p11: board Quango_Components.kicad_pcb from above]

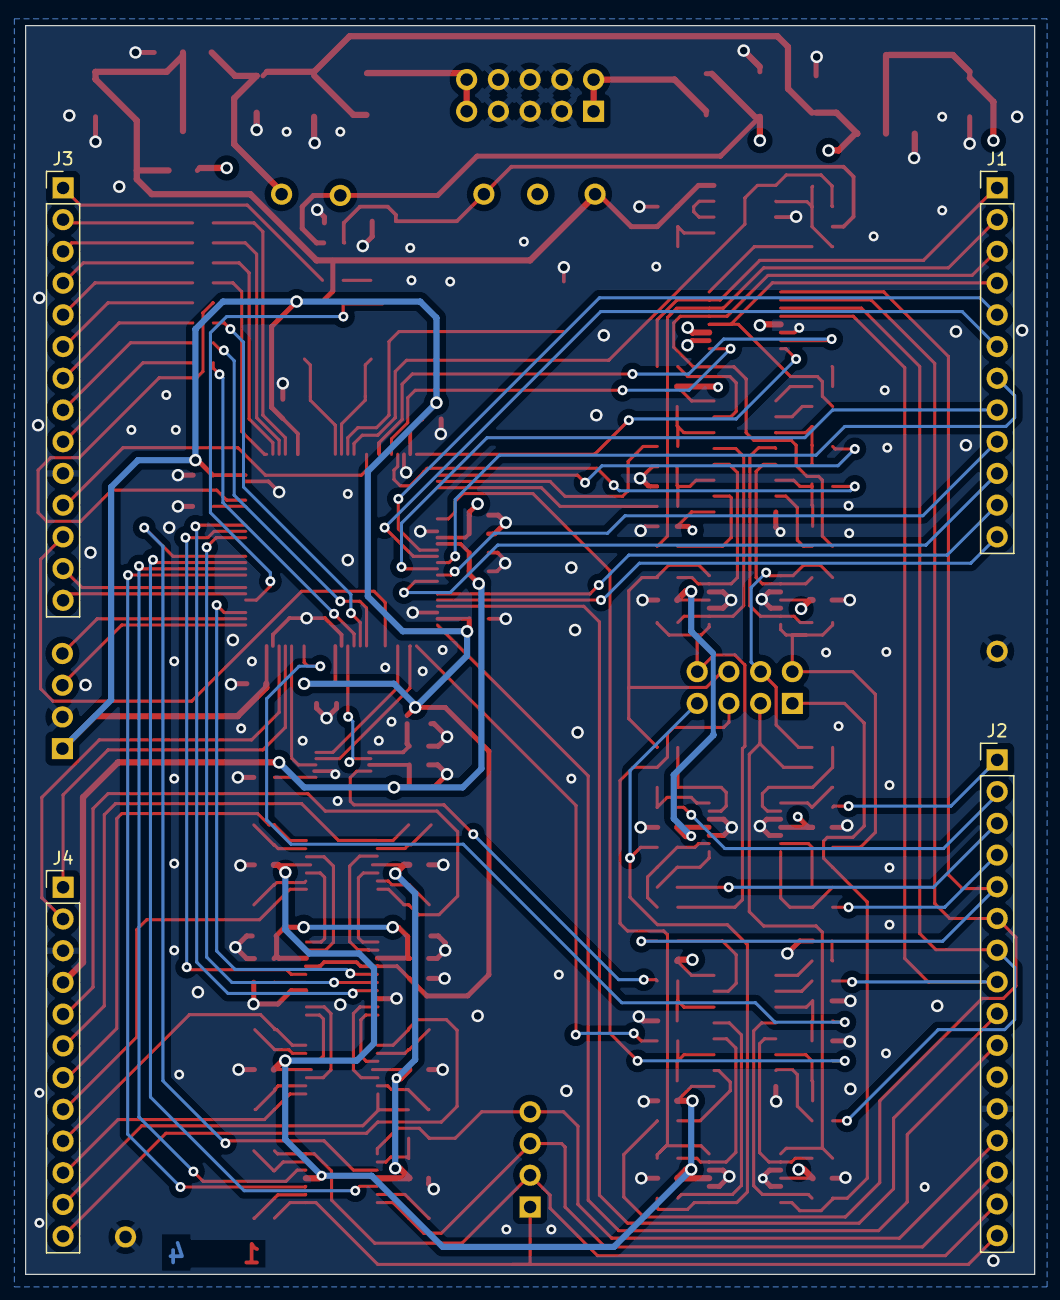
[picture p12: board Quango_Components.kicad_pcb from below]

Board: 4 copper layers, 80.8 x 100.0 mm, 197 parts (4 on the bottom side), 168 nets.

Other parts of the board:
kibuzzard-646A06F2: G***; kibuzzard-646A06F2
kibuzzard-646A061F: G***; kibuzzard-646A061F
kibuzzard-646A076E: G***; kibuzzard-646A076E
kibuzzard-646A0602: G***; kibuzzard-646A0602
kibuzzard-646B91AE: G***; kibuzzard-646B91AE
kibuzzard-646B91BF: G***; kibuzzard-646B91BF
kibuzzard-646B918A: G***; kibuzzard-646B918A
kibuzzard-646B919C: G***; kibuzzard-646B919C
kibuzzard-646B935C: G***; kibuzzard-646B935C
kibuzzard-646B9368: G***; kibuzzard-646B9368

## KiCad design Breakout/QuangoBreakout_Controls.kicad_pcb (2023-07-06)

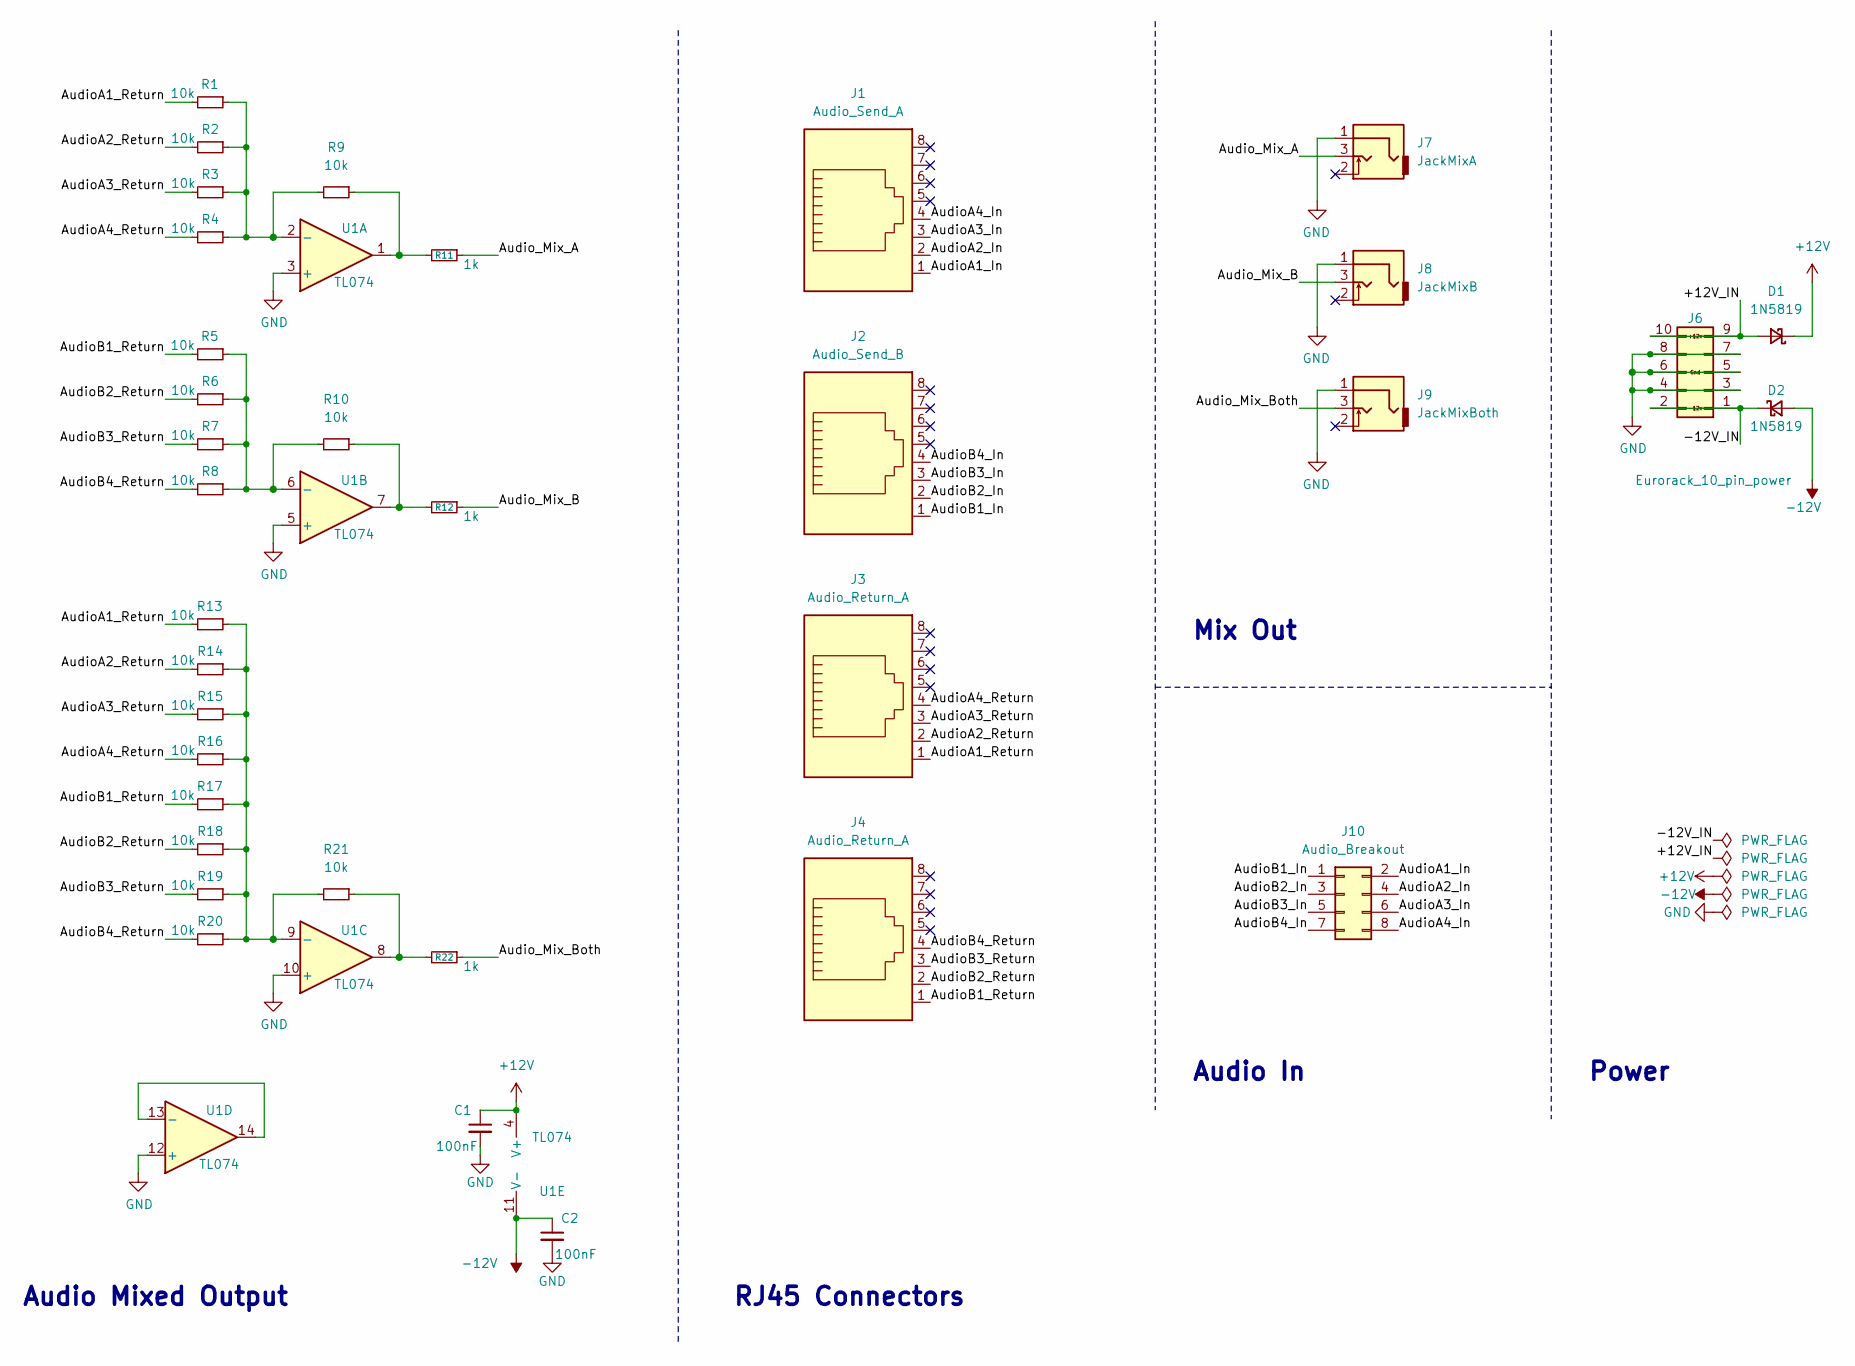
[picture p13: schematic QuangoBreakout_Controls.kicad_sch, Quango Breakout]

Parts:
C1, C2: 100nF; C_0603_1608Metric; Part_Number C23630
D1, D2: 1N5819; D_SOD-123
J1: Audio_Send_A; RJ45_Amphenol_RJHSE-3080
J2: Audio_Send_B; RJ45_Amphenol_RJHSE-3080
J3, J4: Audio_Return_A; RJ45_Amphenol_RJHSE-3080
J6: Eurorack_10_pin_power; PinHeader_2x05_P2.54mm_Vertical
J7: JackMixA; THONKICONN_hole
J8: JackMixB; THONKICONN_hole
J9: JackMixBoth; THONKICONN_hole
J10: Audio_Breakout; PinHeader_2x04_P2.54mm_Vertical
R1, R2, R3, R4, R5, R6, R7, R8, R9, R10, R13, R14, R15, R16, R17, R18, R19, R20, R21: 10k; R_0603_1608Metric; Part_Number C22984
R11, R12, R22: 1k; R_0603_1608Metric; Part_Number C21190
U1: TL074; SOIC-14_3.9x8.7mm_P1.27mm

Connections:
+12V: C1.1, D1.1 (K), U1.4 (V+)
-12V: C2.1, D2.2 (A), U1.11 (V-)
/+12V_IN: D1.2 (A), J6.9, J6.10
/-12V_IN: D2.1 (K), J6.1, J6.2
/AudioA1_In: J1.1, J10.2
/AudioA1_Return: J3.1, R1.2, R13.2
/AudioA2_In: J1.2, J10.4
/AudioA2_Return: J3.2, R2.2, R14.2
/AudioA3_In: J1.3, J10.6
/AudioA3_Return: J3.3, R3.2, R15.2
/AudioA4_In: J1.4, J10.8
/AudioA4_Return: J3.4, R4.2, R16.2
/AudioB1_In: J2.1, J10.1
/AudioB1_Return: J4.1, R5.2, R17.2
/AudioB2_In: J2.2, J10.3
/AudioB2_Return: J4.2, R6.2, R18.2
/AudioB3_In: J2.3, J10.5
/AudioB3_Return: J4.3, R7.2, R19.2
/AudioB4_In: J2.4, J10.7
/AudioB4_Return: J4.4, R8.2, R20.2
/Audio_Mix_A: J7.3, R11.1
/Audio_Mix_B: J8.3, R12.1
/Audio_Mix_Both: J9.3, R22.1
GND: C1.2, C2.2, J6.3, J6.4, J6.5, J6.6, J6.7, J6.8, J7.1, J8.1, J9.1, U1.3 (+), U1.5 (+), U1.10 (+), U1.12 (+)
unnamed: R10.1, R12.2, U1.7
unnamed: R9.1, R11.2, U1.1
unnamed: R21.1, R22.2, U1.8
unnamed: R1.1, R2.1, R3.1, R4.1, R9.2, U1.2 (-)
unnamed: R5.1, R6.1, R7.1, R8.1, R10.2, U1.6 (-)
unnamed: R13.1, R14.1, R15.1, R16.1, R17.1, R18.1, R19.1, R20.1, R21.2, U1.9 (-)
unnamed: U1.13 (-), U1.14

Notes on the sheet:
RJ45 Connectors
Power
Audio Mixed Output
Audio In
Mix Out

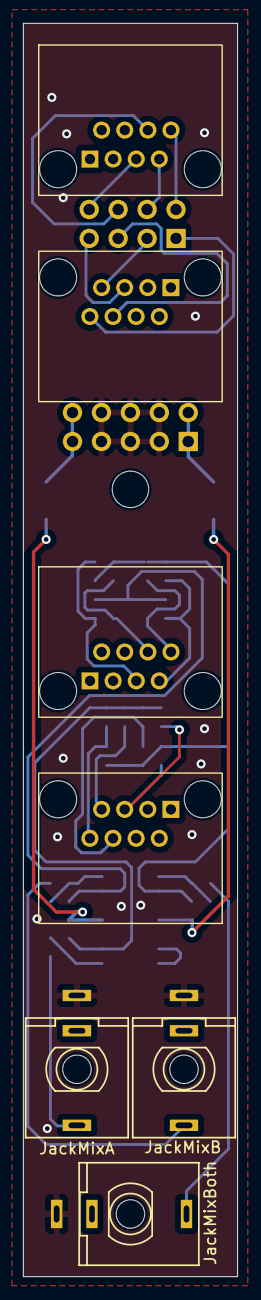
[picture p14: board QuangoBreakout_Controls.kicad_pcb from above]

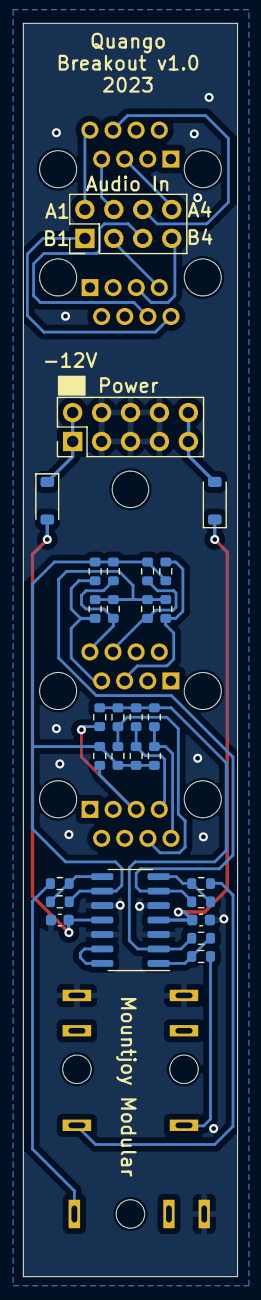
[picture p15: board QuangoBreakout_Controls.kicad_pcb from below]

Board: 2 copper layers, 18.8 x 110.0 mm, 37 parts (29 on the bottom side), 31 nets.

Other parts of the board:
H1: MountingHole; MountingHole_3.2mm_M3_ISO14580

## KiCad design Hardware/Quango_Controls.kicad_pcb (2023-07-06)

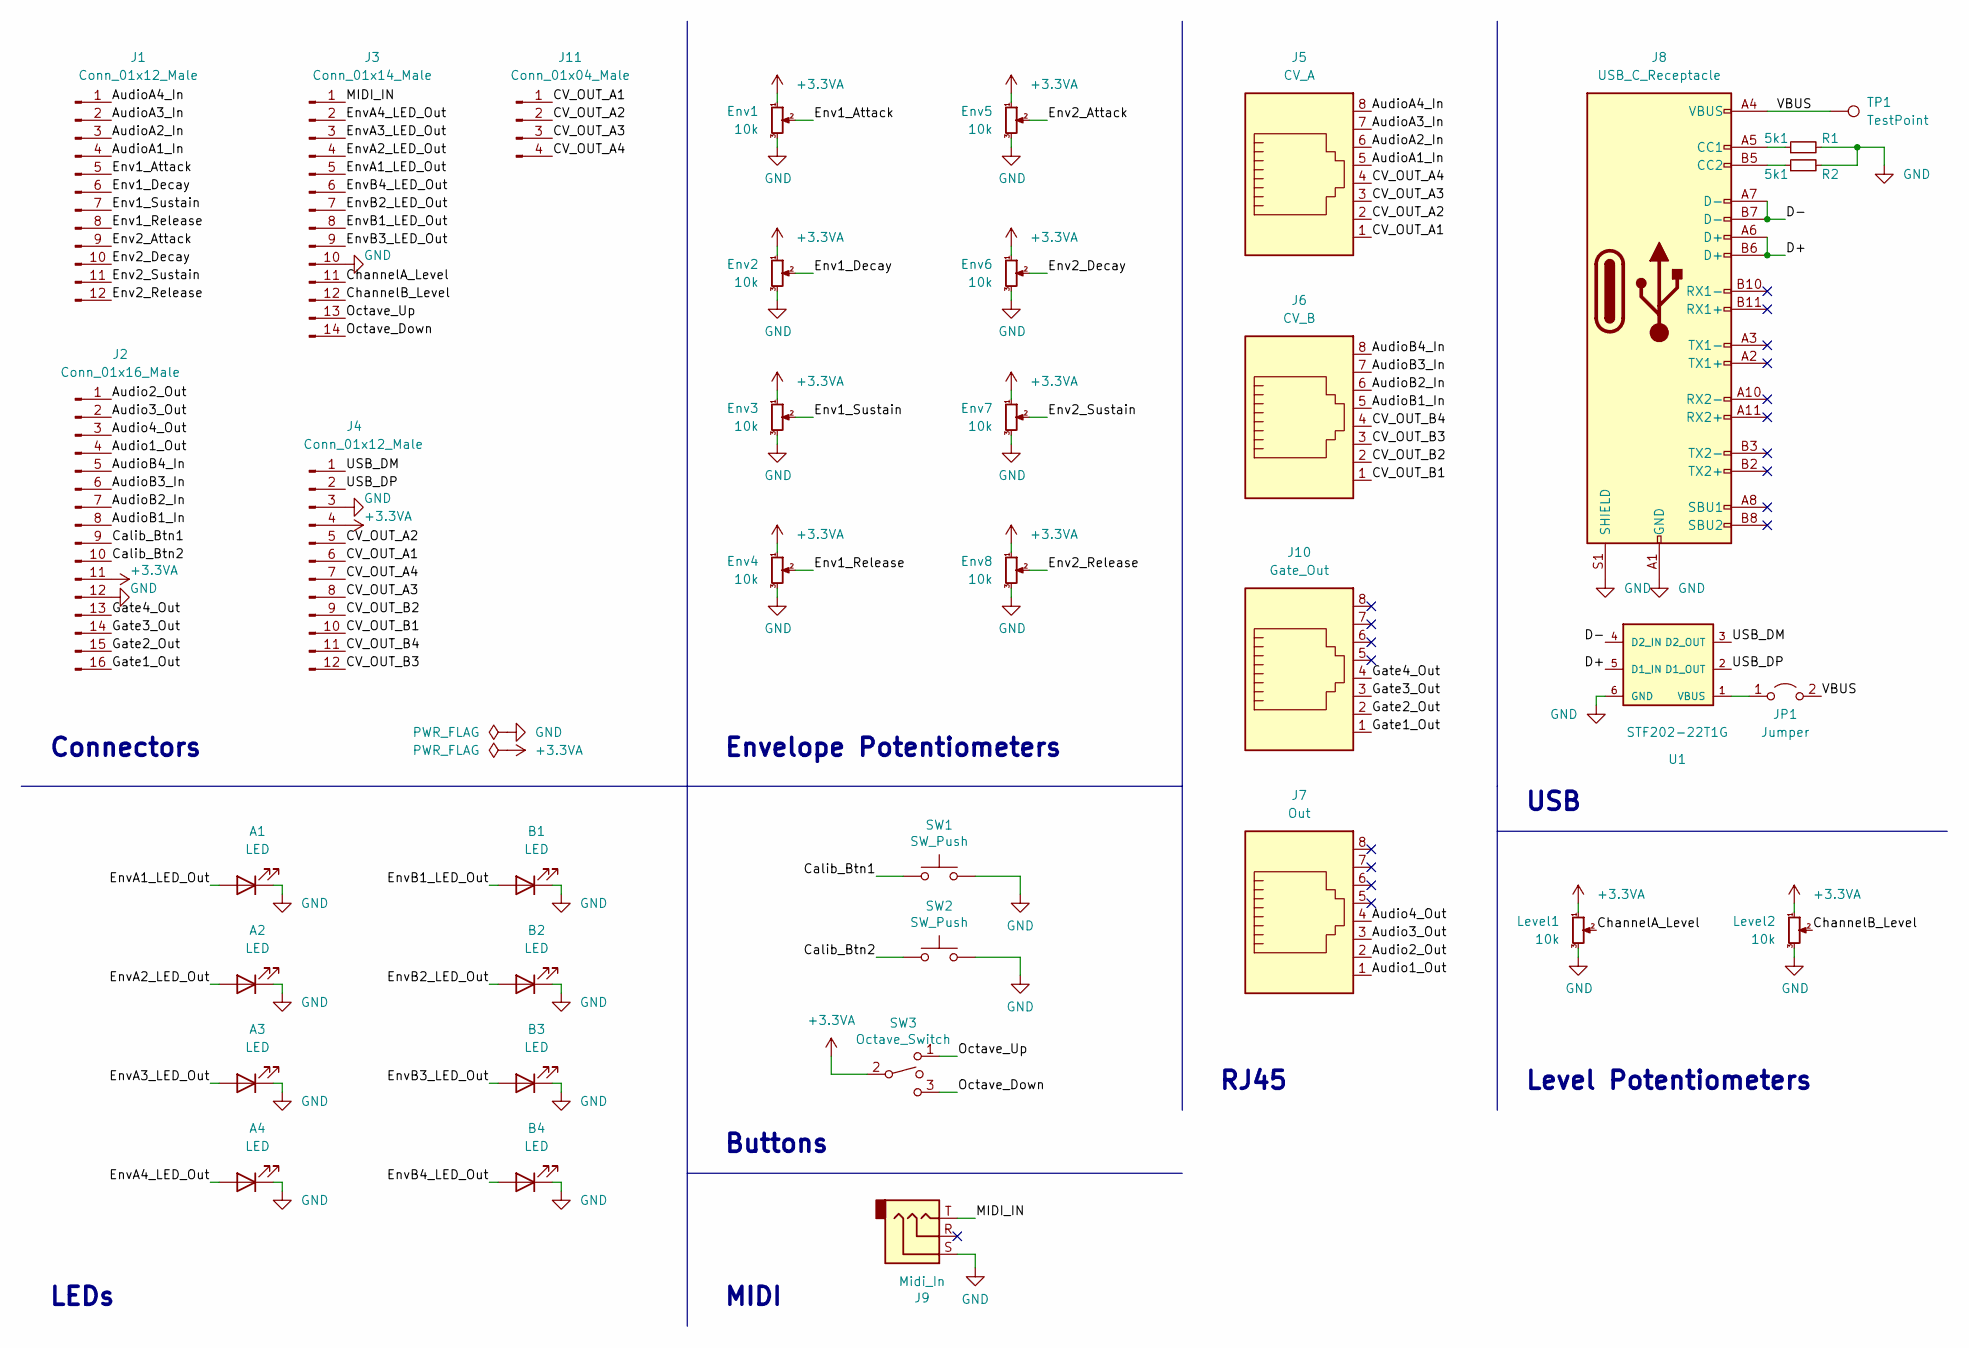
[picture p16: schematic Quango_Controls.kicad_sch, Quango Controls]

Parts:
A1, A2, A3, A4: LED; LED_D3.0mm
B1, B2, B3, B4: LED; LED_D3.0mm
Env1, Env2, Env3, Env4, Env5, Env6, Env7, Env8: 10k; Alpha_9mm_Potentiometer_Aligned
J1, J4: Conn_01x12_Male; PinSocket_1x12_P2.54mm_Vertical
J2: Conn_01x16_Male; PinSocket_1x16_P2.54mm_Vertical
J3: Conn_01x14_Male; PinSocket_1x14_P2.54mm_Vertical
J5: CV_A; RJ45_Molex_42878-8506
J6: CV_B; RJ45_Molex_42878-8506
J7: Out; RJ45_Molex_42878-8506
J8: USB_C_Receptacle; USB_C_Receptacle_Amphenol_12401951E412A
J9: Midi_In; Thonkiconn_Stereo-PJ366ST
J10: Gate_Out; RJ45_Molex_42878-8506
J11: Conn_01x04_Male; PinHeader_1x04_P2.54mm_Vertical
JP1: Jumper; SolderJumper-2_P1.3mm_Open_RoundedPad1.0x1.5mm
Level1, Level2: 10k; Potentiometer_Bourns_PTA4543_Single_Slide
R1, R2: 5k1; R_0805_2012Metric
SW1, SW2: SW_Push; SW_PUSH_6mm_aligned
SW3: Octave_Switch; SP3T_Mini_Switch
TP1: TestPoint; PinSocket_1x01_P2.54mm_Vertical
U1: STF202-22T1G

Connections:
+3.3VA: Env1.1, Env2.1, Env3.1, Env4.1, Env5.1, Env6.1, Env7.1, Env8.1, J2.11, J4.4, Level1.1, Level2.1, SW3.2
/Audio1_Out: J2.4, J7.1
/Audio2_Out: J2.1, J7.2
/Audio3_Out: J2.2, J7.3
/Audio4_Out: J2.3, J7.4
/AudioA1_In: J1.4, J5.5
/AudioA2_In: J1.3, J5.6
/AudioA3_In: J1.2, J5.7
/AudioA4_In: J1.1, J5.8
/AudioB1_In: J2.8, J6.5
/AudioB2_In: J2.7, J6.6
/AudioB3_In: J2.6, J6.7
/AudioB4_In: J2.5, J6.8
/CV_OUT_A1: J4.6, J5.1, J11.1
/CV_OUT_A2: J4.5, J5.2, J11.2
/CV_OUT_A3: J4.8, J5.3, J11.3
/CV_OUT_A4: J4.7, J5.4, J11.4
/CV_OUT_B1: J4.10, J6.1
/CV_OUT_B2: J4.9, J6.2
/CV_OUT_B3: J4.12, J6.3
/CV_OUT_B4: J4.11, J6.4
/Calib_Btn1: J2.9, SW1.1
/Calib_Btn2: J2.10, SW2.1
/ChannelA_Level: J3.11, Level1.2
/ChannelB_Level: J3.12, Level2.2
/D+: J8.A6 (D+), J8.B6 (D+), U1.5 (D1_IN)
/D-: J8.A7 (D-), J8.B7 (D-), U1.4 (D2_IN)
/Env1_Attack: Env1.2, J1.5
/Env1_Decay: Env2.2, J1.6
/Env1_Release: Env4.2, J1.8
/Env1_Sustain: Env3.2, J1.7
/Env2_Attack: Env5.2, J1.9
/Env2_Decay: Env6.2, J1.10
/Env2_Release: Env8.2, J1.12
/Env2_Sustain: Env7.2, J1.11
/EnvA1_LED_Out: A1.2 (A), J3.5
/EnvA2_LED_Out: A2.2 (A), J3.4
/EnvA3_LED_Out: A3.2 (A), J3.3
/EnvA4_LED_Out: A4.2 (A), J3.2
/EnvB1_LED_Out: B1.2 (A), J3.8
/EnvB2_LED_Out: B2.2 (A), J3.7
/EnvB3_LED_Out: B3.2 (A), J3.9
/EnvB4_LED_Out: B4.2 (A), J3.6
/Gate1_Out: J2.16, J10.1
/Gate2_Out: J2.15, J10.2
/Gate3_Out: J2.14, J10.3
/Gate4_Out: J2.13, J10.4
/MIDI_IN: J3.1, J9.T
/Octave_Down: J3.14, SW3.3
/Octave_Up: J3.13, SW3.1
/USB_DM: J4.1, U1.3 (D2_OUT)
/USB_DP: J4.2, U1.2 (D1_OUT)
/VBUS: J8.A4 (VBUS), J8.A9 (VBUS), J8.B4 (VBUS), J8.B9 (VBUS), JP1.2 (B), TP1.1
GND: A1.1 (K), A2.1 (K), A3.1 (K), A4.1 (K), B1.1 (K), B2.1 (K), B3.1 (K), B4.1 (K), Env1.3, Env2.3, Env3.3, Env4.3, Env5.3, Env6.3, Env7.3, Env8.3, J2.12, J3.10, J4.3, J8.A1 (GND), J8.A12 (GND), J8.B1 (GND), J8.B12 (GND), J8.S1 (SHIELD), J9.S, Level1.3, Level2.3, R1.2, R2.2, SW1.2, SW2.2, U1.6 (GND)
unnamed: J8.A5 (CC1), R1.1
unnamed: J8.B5 (CC2), R2.1
unnamed: JP1.1 (A), U1.1 (VBUS)

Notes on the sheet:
Buttons
Connectors
RJ45
USB
Level Potentiometers
Envelope Potentiometers
LEDs
MIDI

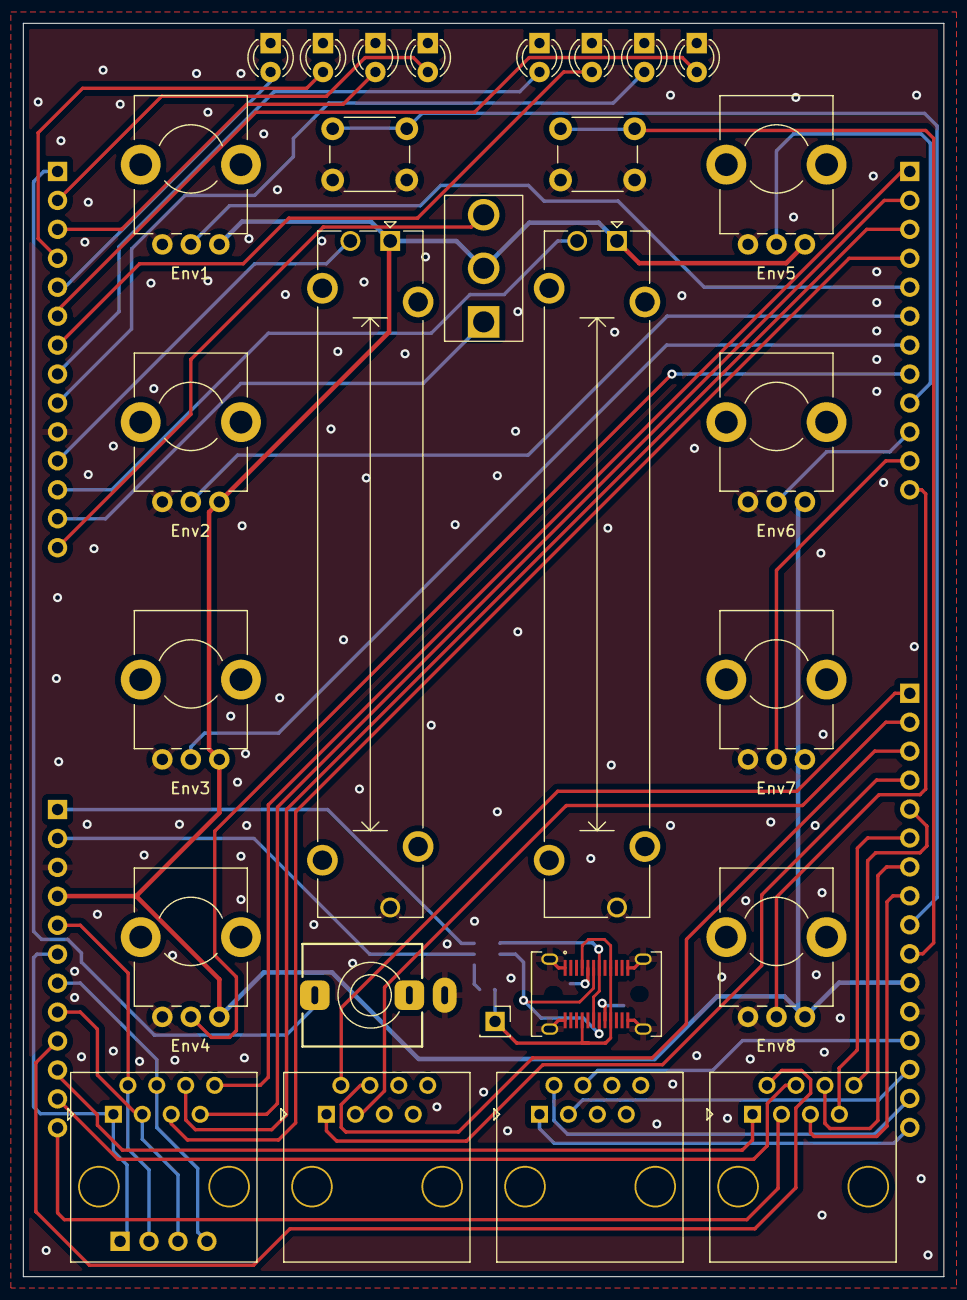
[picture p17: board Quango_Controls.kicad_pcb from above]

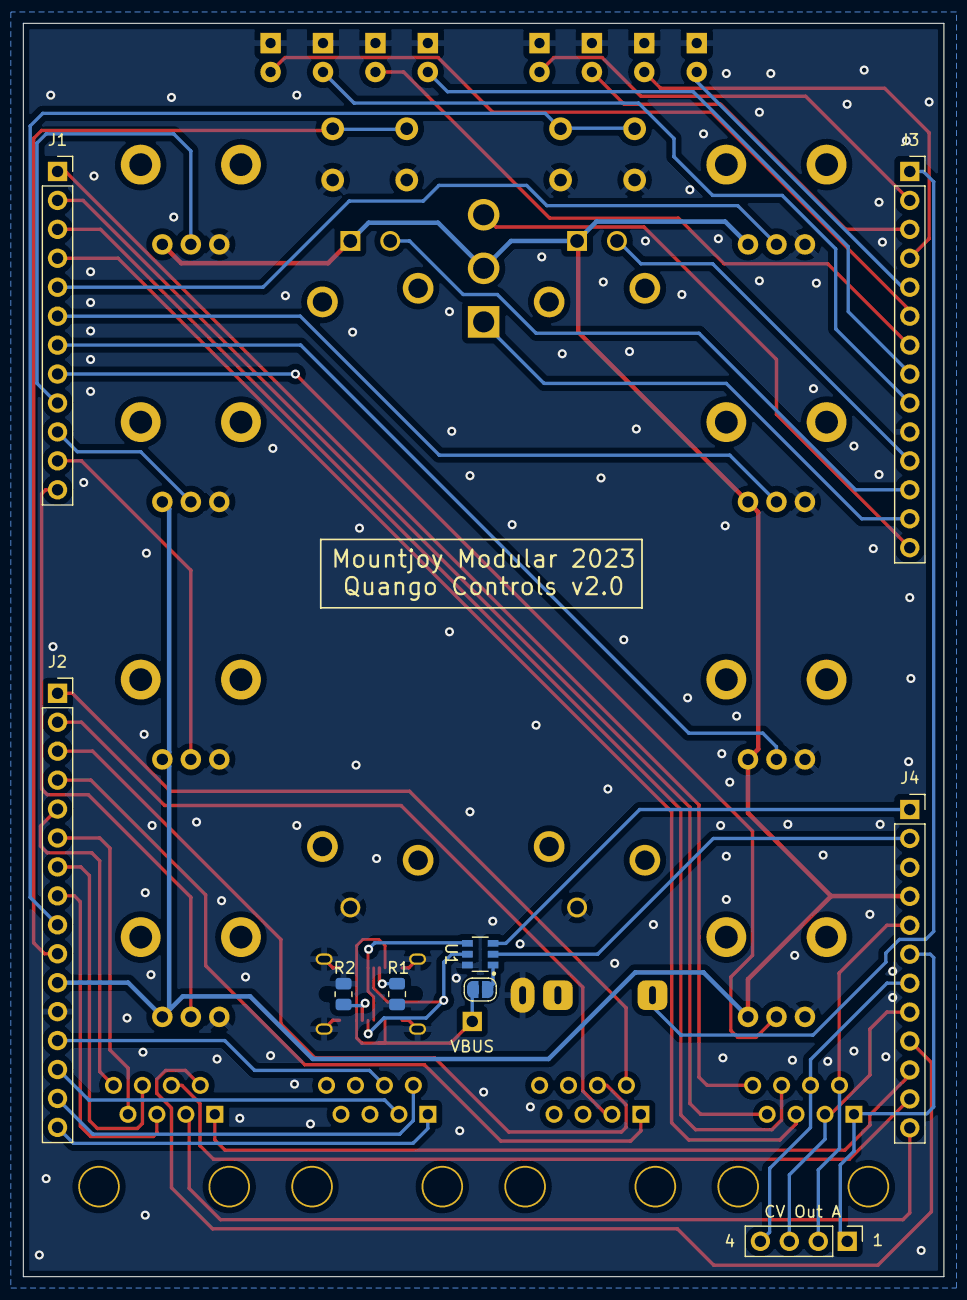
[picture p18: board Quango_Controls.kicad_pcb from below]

Board: 2 copper layers, 80.8 x 110.0 mm, 37 parts (9 on the bottom side), 57 nets.

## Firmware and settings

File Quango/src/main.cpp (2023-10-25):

#include "calib.h"
#include "initialisation.h"
#include "usb.h"
#include "VoiceManager.h"
#include "configManager.h"

volatile uint32_t SysTickVal;
volatile ADCValues adc;


Config config{&calib.configSaver};		// Initialise configuration to handle saving and restoring calibration settings


extern "C" {
#include "interrupts.h"
}


extern uint32_t SystemCoreClock;
int main(void)
{
	SystemInit();						// Activates floating point coprocessor and resets clock
	InitClocks();						// Configure the clock and PLL
	InitHardware();
	voiceManager.Init();				// Initialises external DACs
	usb.InitUSB();
	config.RestoreConfig();

	while (1) {
		usb.cdc.ProcessCommand();		// Check for incoming USB serial commands
	}
}

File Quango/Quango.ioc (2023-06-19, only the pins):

Mcu.UserName=STM32G473VETx
PA11.Signal=USB_DM
PA12.Signal=USB_DP
PC0.Signal=ADC1_IN6
PE10.Signal=ADC3_IN14
PE7.Signal=ADC3_IN4
PE8.Signal=ADC3_IN6
PE9.Signal=ADC3_IN2
PF0-OSC_IN.Signal=RCC_OSC_IN
PF1-OSC_OUT.Signal=RCC_OSC_OUT

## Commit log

2023-04-20 Schematic Updates
    [Quango_Components.kicad_sch]
2023-04-21 Added LEDs & Sliders
    [Quango_Panel.kicad_pcb, Quango_Panel.kicad_sch]
2023-04-24 More schematic updates
    [Quango_Components.kicad_sch, Quango_Panel.kicad_pcb]
2023-05-06 Moved OpAmps to separate schematic page
    [OpAmps.kicad_sch, Quango_Components.kicad_sch]
2023-05-06 Started laying out component PCB
    [OpAmps.kicad_sch, Quango_Components.kicad_pcb, Quango_Components.kicad_sch]
2023-05-07 Started op-amp layout
    [OpAmps.kicad_sch, Quango_Components.kicad_pcb, Quango_Components.kicad_sch]
2023-05-07 Layout of audio vca section
    [OpAmps.kicad_sch, Quango_Components.kicad_pcb, Quango_Components.kicad_sch]
2023-05-08 Further Layout
    [Quango_Components.kicad_pcb, Quango_Components.kicad_sch]
2023-05-10 Main components positioned
    [OpAmps.kicad_sch, Quango_Components.kicad_pcb, Quango_Components.kicad_sch]
2023-05-10 Added LED resistors
    [Quango_Components.kicad_pcb, Quango_Components.kicad_sch]
2023-05-11 More Layout
    [Quango_Components.kicad_pcb, Quango_Components.kicad_sch]
2023-05-15 First draft of signal routing done
    [Quango_Components.kicad_pcb, Quango_Components.kicad_sch]
2023-05-16 Started laying out control board
    [Quango_Components.kicad_pcb, Quango_Controls.kicad_pcb, Quango_Controls.kicad_sch]
2023-05-16 Reduced module size to 14HP; updated to Amphenol USB C
    [Quango_Components.kicad_pcb, Quango_Controls.kicad_pcb, Quango_Controls.kicad_sch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]
2023-05-16 Added individual audio channel breakout
    [OpAmps.kicad_sch, Quango_Components.kicad_pcb, Quango_Components.kicad_sch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]
2023-05-17 Routing Power traces
    [OpAmps.kicad_sch, Quango_Components.kicad_pcb, Quango_Components.kicad_sch]
2023-05-17 Added Test Points
    [OpAmps.kicad_sch, Quango_Components.kicad_pcb, Quango_Components.kicad_sch]
2023-05-17 Preparing panel and control board for routing
    [Quango_Components.kicad_pcb, Quango_Controls.kicad_pcb, Quango_Panel.kicad_pcb]
2023-05-18 First draft routing of control board
    [Quango_Components.kicad_pcb, Quango_Components.kicad_sch, Quango_Controls.kicad_pcb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]
2023-05-18 Cleaned up Components schematic
    [Quango_Components.kicad_pcb, Quango_Components.kicad_sch]
2023-05-18 Schematic Clean Up
    [OpAmps.kicad_sch, Quango_Components.kicad_sch, Quango_Controls.kicad_sch]
2023-05-19 Added Gate ouputs to component board
    [OpAmps.kicad_sch, Quango_Components.kicad_pcb, Quango_Components.kicad_sch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]
2023-05-19 Updating Controls and Panel to support gates
    [Quango_Components.kicad_pcb, Quango_Components.kicad_sch, Quango_Controls.kicad_pcb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]
2023-05-20 Increased size to 16HP
    [Quango_Components.kicad_pcb, Quango_Controls.kicad_pcb, Quango_Controls.kicad_sch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]
2023-05-20 Added breakout for gates on component board
    [OpAmps.kicad_sch, Quango_Components.kicad_pcb, Quango_Components.kicad_sch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]
2023-05-21 Fixed OpAmp Power supply; component board annotations
    [OpAmps.kicad_sch, Quango_Components.kicad_pcb, Quango_Components.kicad_sch]
2023-05-21 Clean Up of Panel and Control boards
    [Quango_Components.kicad_pcb, Quango_Controls.kicad_pcb, Quango_Panel.kicad_pcb]
2023-05-22 Set up JLC parts placement details
    [Quango_Components-B_Cu.gbr, Quango_Components-B_Mask.gbr, Quango_Components-B_Paste.gbr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]
2023-05-22 Updates to Panel Graphics
    [Quango_Components-B_Cu.gbr, Quango_Components-B_Mask.gbr, Quango_Components-B_Paste.gbr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]
2023-05-23 Final Updates for v1.0 production
    [Quango_Components-B_Cu.gbr, Quango_Components-B_Mask.gbr, Quango_Components-B_Paste.gbr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]
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2023-06-03 Timer 4 PWM Configured and Working
    [Quango_Components.kicad_sch]
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2023-06-05 Multiplexer tested working; PCB bug - U14 power rails inverted
    [OpAmps.kicad_sch, Quango_Components.kicad_sch]
2023-06-07 Started implementing voice and envelope handling mechanism
    [Quango_Components.kicad_pcb]
2023-06-08 Gate mechanism working
    [OpAmps.kicad_sch]
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2023-06-09 Refined gate and envelope handling to retrigger correctly when note stealing
    [VoiceManager.cpp, envelope.cpp]
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2023-06-15 Fixed some volatile issues at higher compiler optimisation level
    [VoiceManager.cpp, calib.cpp, calib.h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]
2023-06-15 Started reworking USB descriptor handling
    [USB.h]
2023-06-16 Added UART output for outputting USB debug info
    [USB_CDC.xlsx]
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2023-06-18 Serial handler fully replaced with CDC handler
    [USB.h, main.cpp]
2023-06-18 Started reorganising PMA allocation and endpoint activation
    Still issues setting PMA addresses for EP0
    [USB.h]
2023-06-19 PMA Addresses configured correctly
    [Quango.ioc, USB.h]
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2023-06-20 Increased CV output range from 6v - 7.13v to increase maximum output octave
    [OpAmps.kicad_sch, Quango_Components.kicad_sch]
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2023-06-23 Altered interrupt priority as some UART MIDI notes were being missed
    Note this could cause issues as midi note may fire setting envelope gate state which will then be overwritten in the envelope calculation.
    Also increased envelope timer frequency to 20kHz.
    [VoiceManager.cpp, initialisation.cpp, main.cpp]
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2023-06-25 Started designing breakout send/receive board
    [QuangoBreakout_Controls.kicad_pcb, QuangoBreakout_Controls.kicad_sch, QuangoBreakout_Panel.kicad_pcb]
2023-06-25 Updated to Kicad 7.05
    [QuangoBreakout_Controls.kicad_pcb]
2023-06-25 Terminated unused op-amp
    [QuangoBreakout_Controls.kicad_pcb, QuangoBreakout_Controls.kicad_sch, QuangoBreakout_Panel.kicad_pcb]
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2023-06-29 Updated controls to include octave switching; revised panel
    [Quango_Controls.kicad_pcb, Quango_Controls.kicad_sch, Quango_Panel.kicad_pcb]
2023-07-06 Prepared v2 controls and panel for manufacture
    [Quango_Components.kicad_sch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]
2023-07-06 Added header on control board for CV output
    [QuangoBreakout_Controls.kicad_sch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]
2023-07-06 Added Breakout gerbers; Added pdfs of schematics
    [QuangoBreakout_Controls-B_Cu.gbr, QuangoBreakout_Controls-B_Mask.gbr, QuangoBreakout_Controls-B_Silkscreen.gbr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]
2023-07-15 Implemented octave up/down switch
    Toggle CS on SPI2 to fix intermittent issue with external DAC
    [Quango_Controls.kicad_sch]
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2023-09-14 Added v3 panel gerbers
    [Quango_Panel_3-B_Cu.gbr, Quango_Panel_3-B_Mask.gbr, Quango_Panel_3-B_Silkscreen.gbr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]
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2023-10-23 Fixed bug with calibration button presses
    [calib.cpp, initialisation.cpp, main.cpp]
2023-10-23 Fixed bug in config saving where config page would overrun
    [calib.cpp, calib.h, main.cpp]
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2023-10-28 Fixed bug in calibration not clearing offsets before running
    [calib.cpp]
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2024-10-02 Fixed bug overflow and interrupt priority bug in midi queue handling
    [USB.h, VoiceManager.cpp, initialisation.cpp]
2024-10-02 Updated component schematic/pcb to v2
    Kicad 8.0
    Fixing opamp U14 power reversal
    [OpAmps.kicad_sch, Quango_Components.kicad_pcb, Quango_Components.kicad_sch]
